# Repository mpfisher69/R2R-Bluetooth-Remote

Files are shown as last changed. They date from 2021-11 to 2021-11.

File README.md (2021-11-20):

<h1> Bluetooth Remote Controller</h1>
<p>For Reel-to-Reel tape recorders and vintage cassette decks.</p>
<p>Works with any open-reel (reel-to-reel) tape deck equipped with remote control connector, with active-low inputs</p>
It replicates functionality of original Technics remote controllers such as RP-9690 and RP-070 (including reverse-play function).</br>
Connects to remote controller input on Technics RS1500, RS1506 and RS1700 and also on Akai GX-635, GX-636, GX-747, GX-747DBX, GX-77 and also vintage cassette decks.</br>
This Bluetooth remote can be wired to other makes and models of tape machines, as long as they are equipped with a "tactile" tape transport buttons and "active-low" logic, such as Pioneer RT909.</p>

<p>Screenshots:<br>
<br>
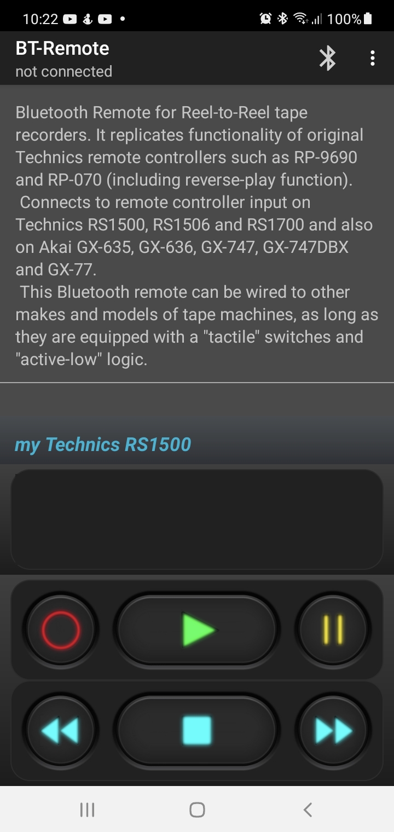
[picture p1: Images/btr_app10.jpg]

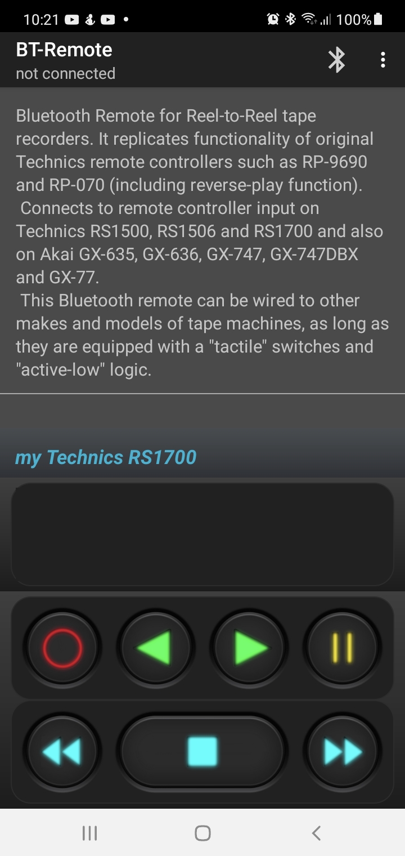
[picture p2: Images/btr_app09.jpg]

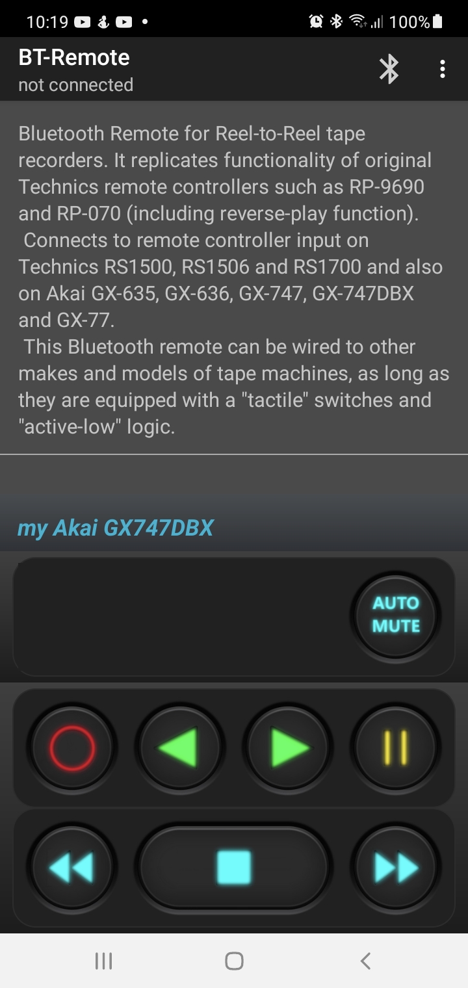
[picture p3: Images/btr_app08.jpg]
</p>
<p> I have some of the receivers fully built, if you don't want to build one yourself.<br>
Please <a href="mailto:audio@mpfisher.com">contact me</a> for details.<br>
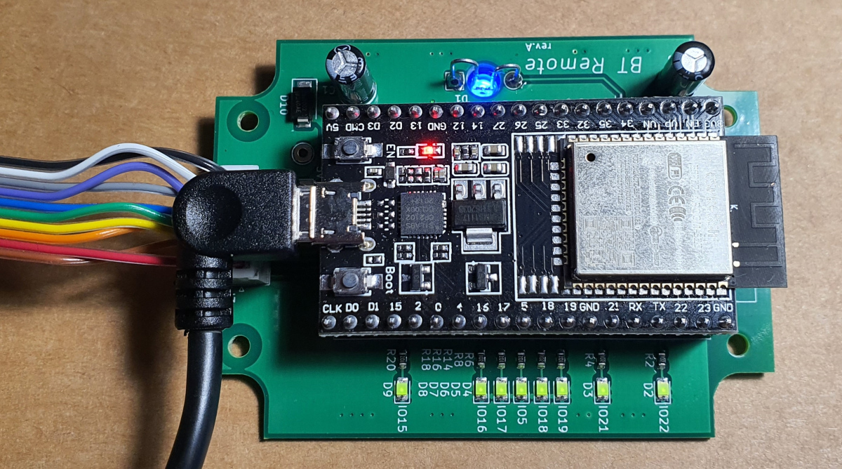
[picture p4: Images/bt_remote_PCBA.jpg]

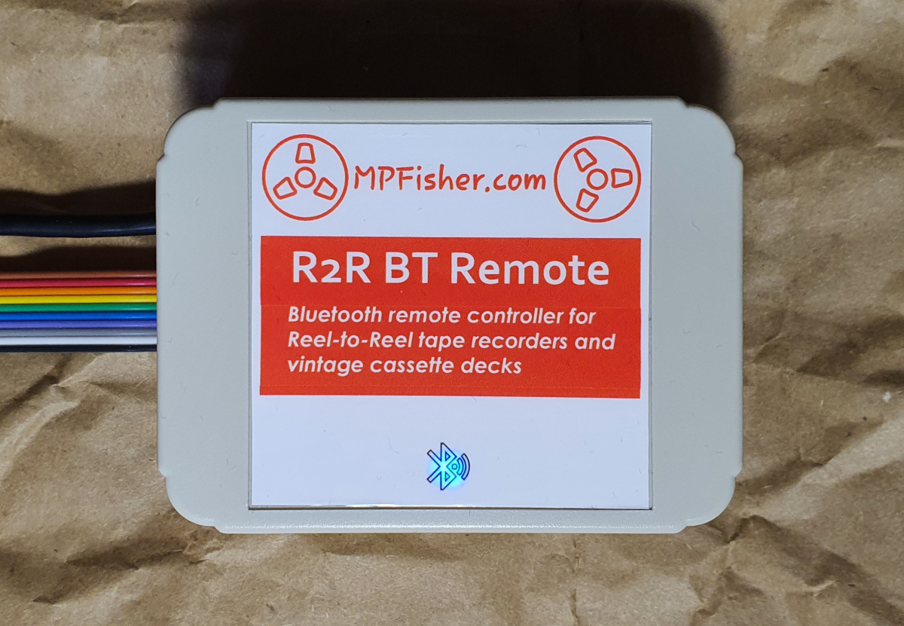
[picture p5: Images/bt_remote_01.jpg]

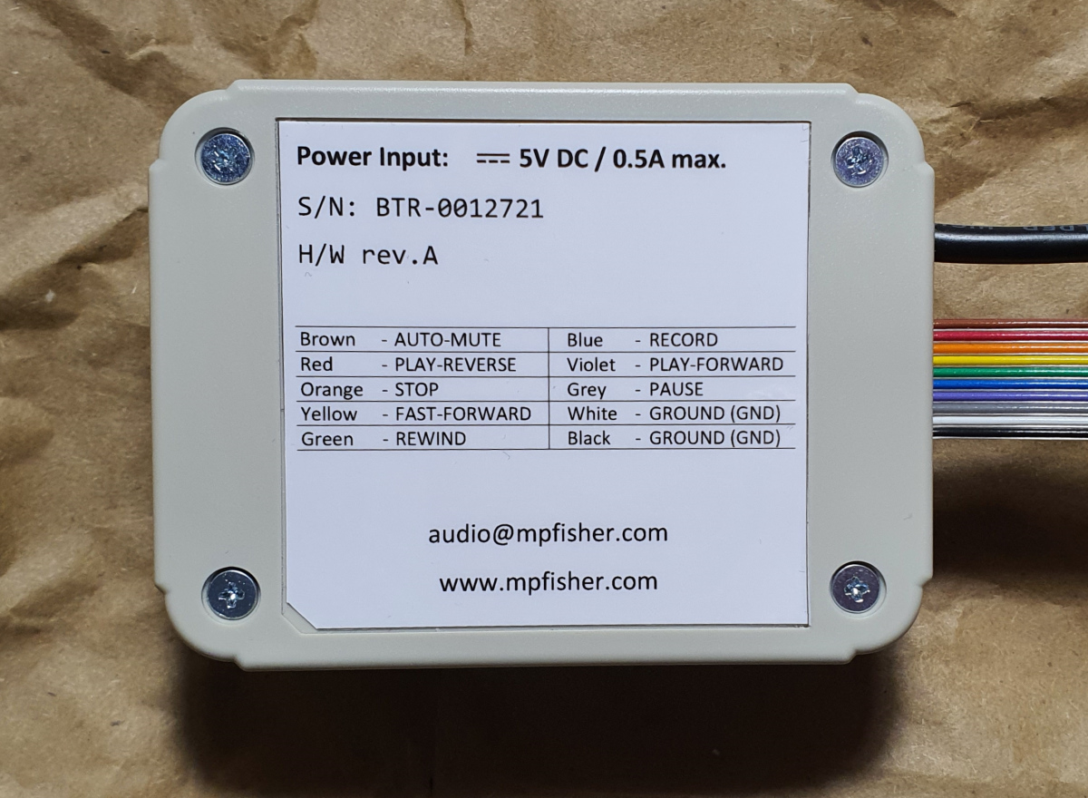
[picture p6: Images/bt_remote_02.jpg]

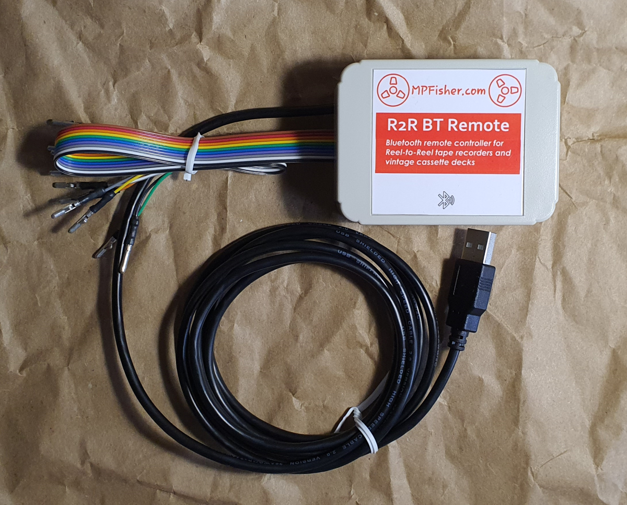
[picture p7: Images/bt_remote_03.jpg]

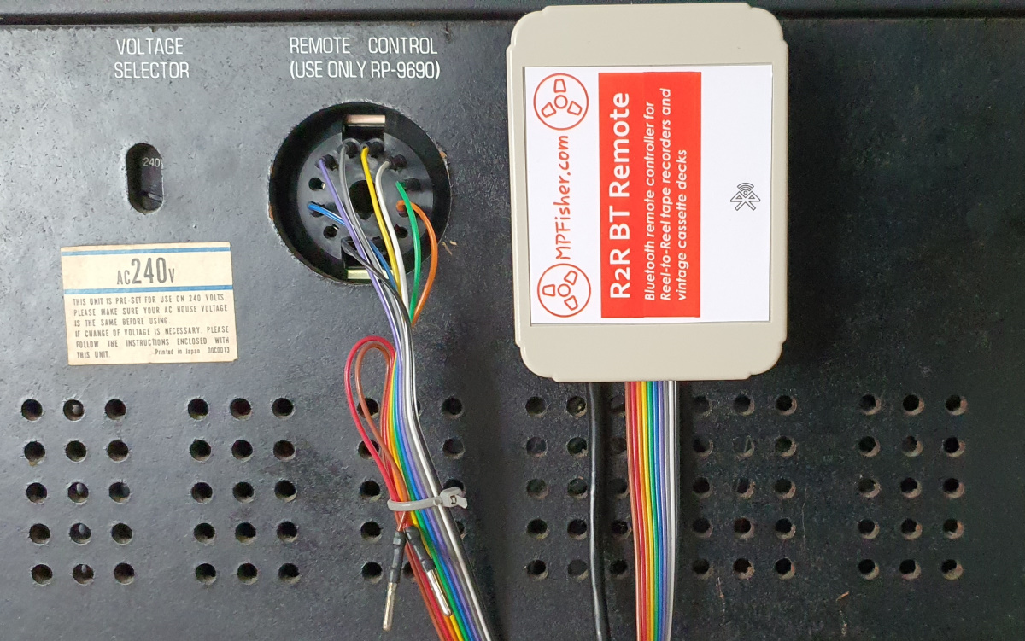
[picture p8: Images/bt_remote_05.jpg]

</p>

<p>Software is provided "as is" without any guarantee. I am looking for a colaborators who would want to develop it further and also help develop iOS app for iPhone/iPad.</p>
<p>To-Do:

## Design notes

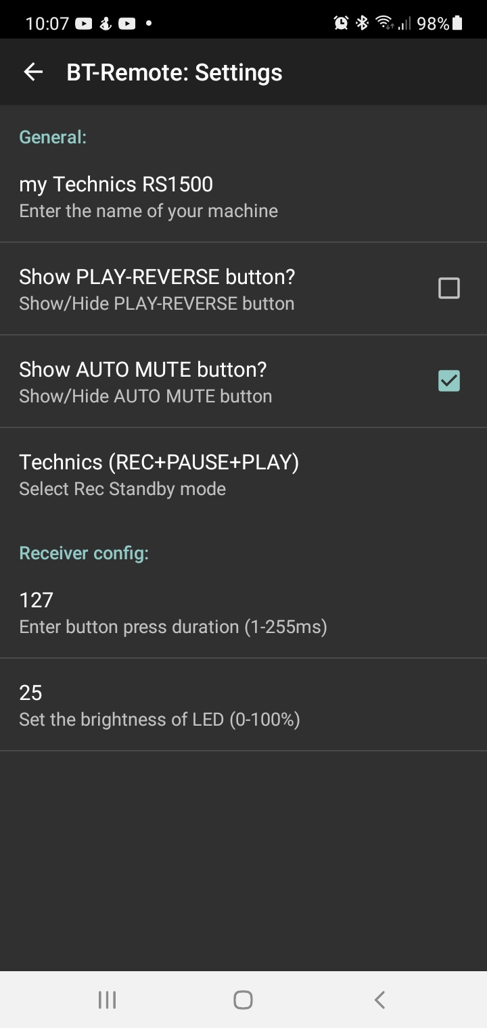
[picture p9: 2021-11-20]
Images/btr_app05.jpg

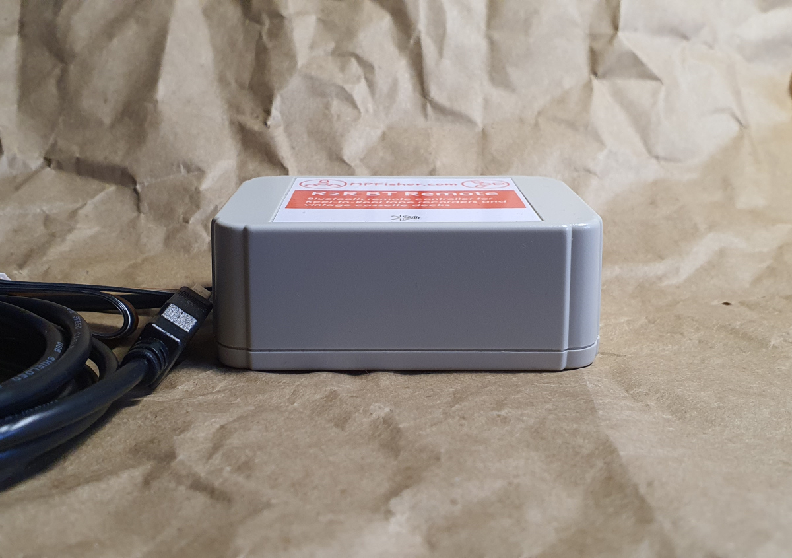
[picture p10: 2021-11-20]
Images/bt_remote_04.jpg

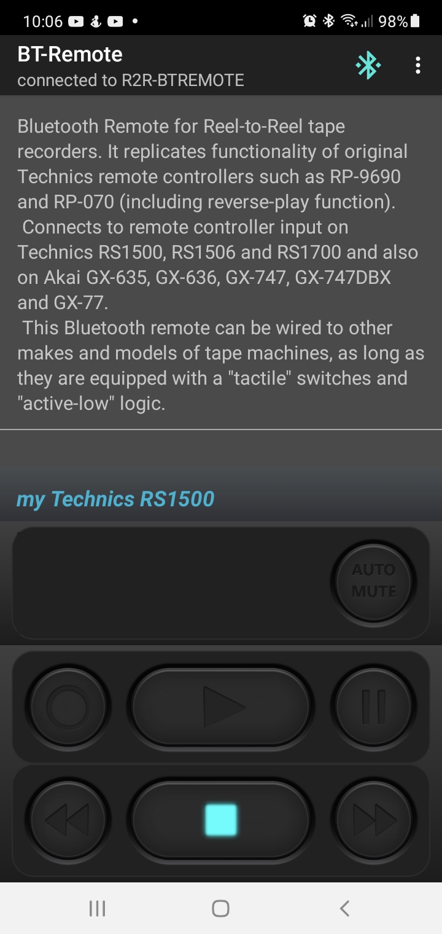
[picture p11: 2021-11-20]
Images/btr_app03.jpg

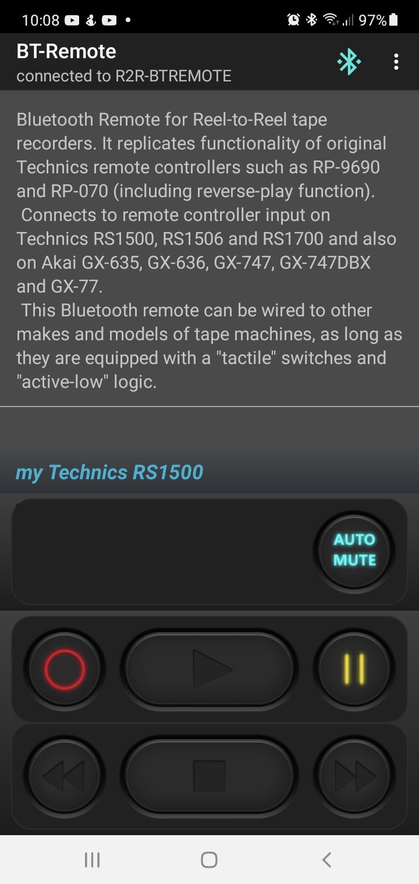
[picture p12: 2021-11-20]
Images/btr_app07.jpg

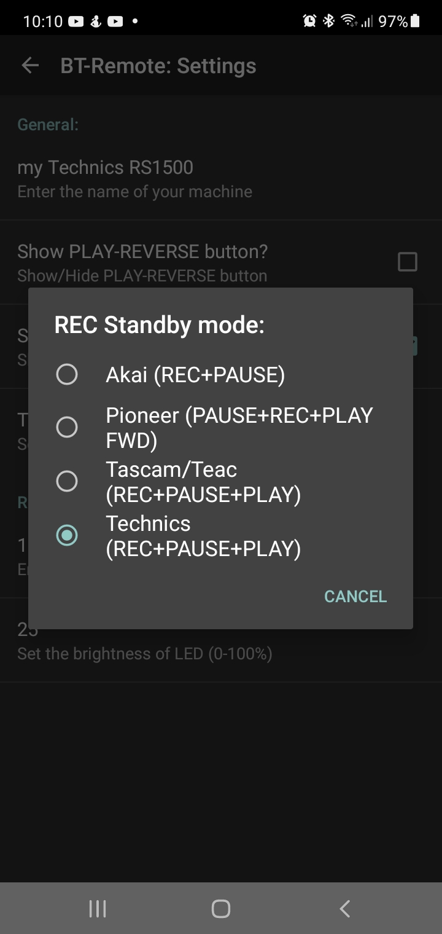
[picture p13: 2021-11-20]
Images/btr_app06.jpg

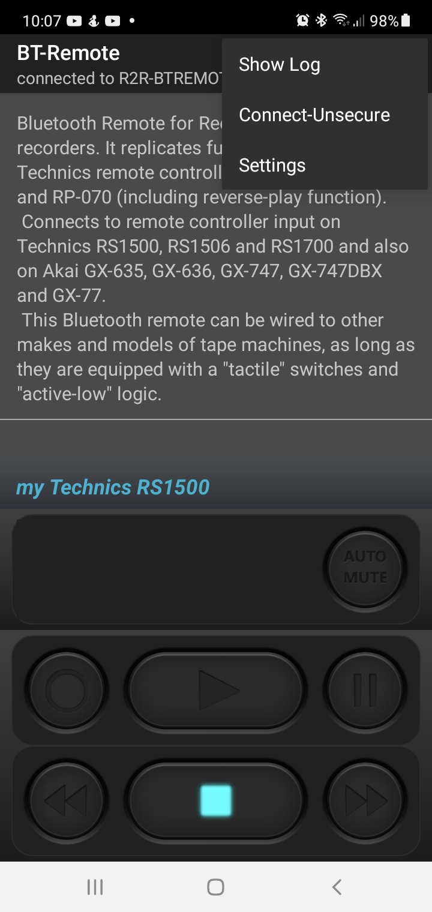
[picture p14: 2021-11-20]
Images/btr_app04.jpg

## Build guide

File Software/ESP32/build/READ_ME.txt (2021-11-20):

For ESP32 the flash must be written as follows:
erase range: 
0x8000 to 0x8FFF
0x1000 to 0x7FFF
0x10000 to 0xABFFF

0x8000: partition-table.bin
0x1000: bootloader.bin
0x10000: bt_remote.bin

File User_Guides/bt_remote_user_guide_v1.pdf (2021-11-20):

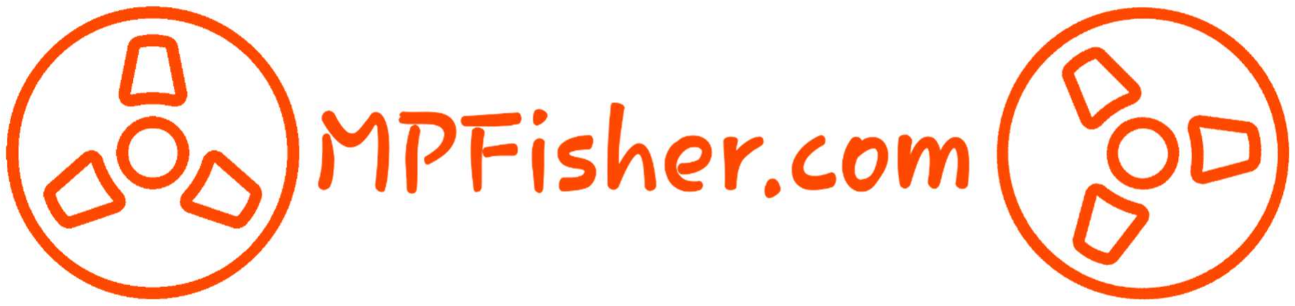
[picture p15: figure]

# R2R BT-Remote

## User Guide

ver.1
23/08/2021

## Hardware Installation

Switch off the power to the tape recorder and connect the receiver according to the wiring diagrams presented below.

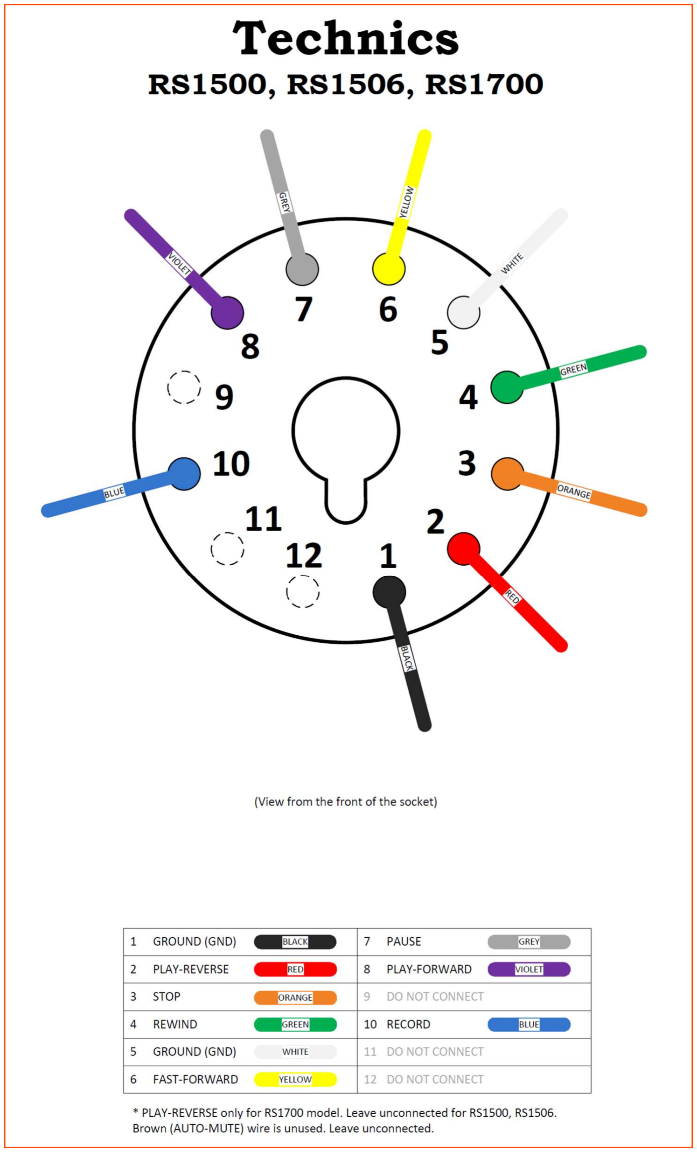
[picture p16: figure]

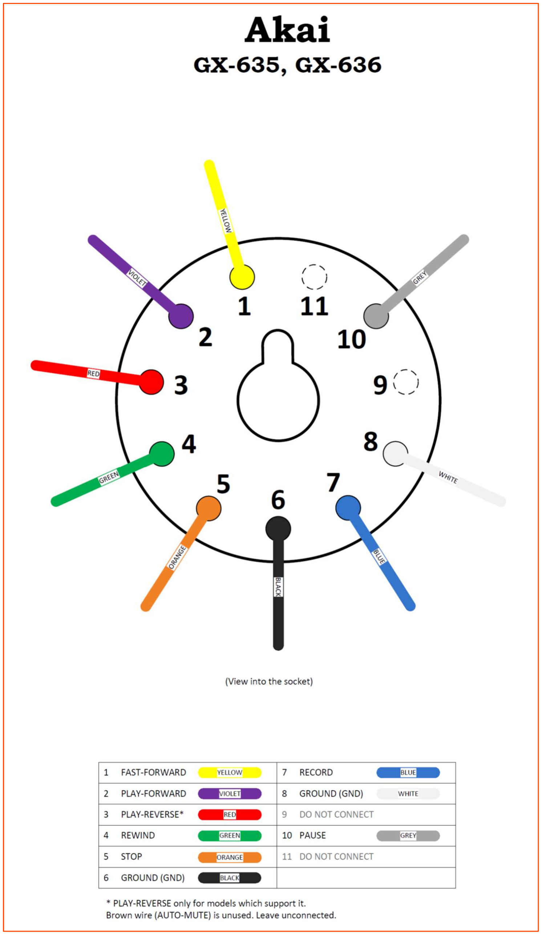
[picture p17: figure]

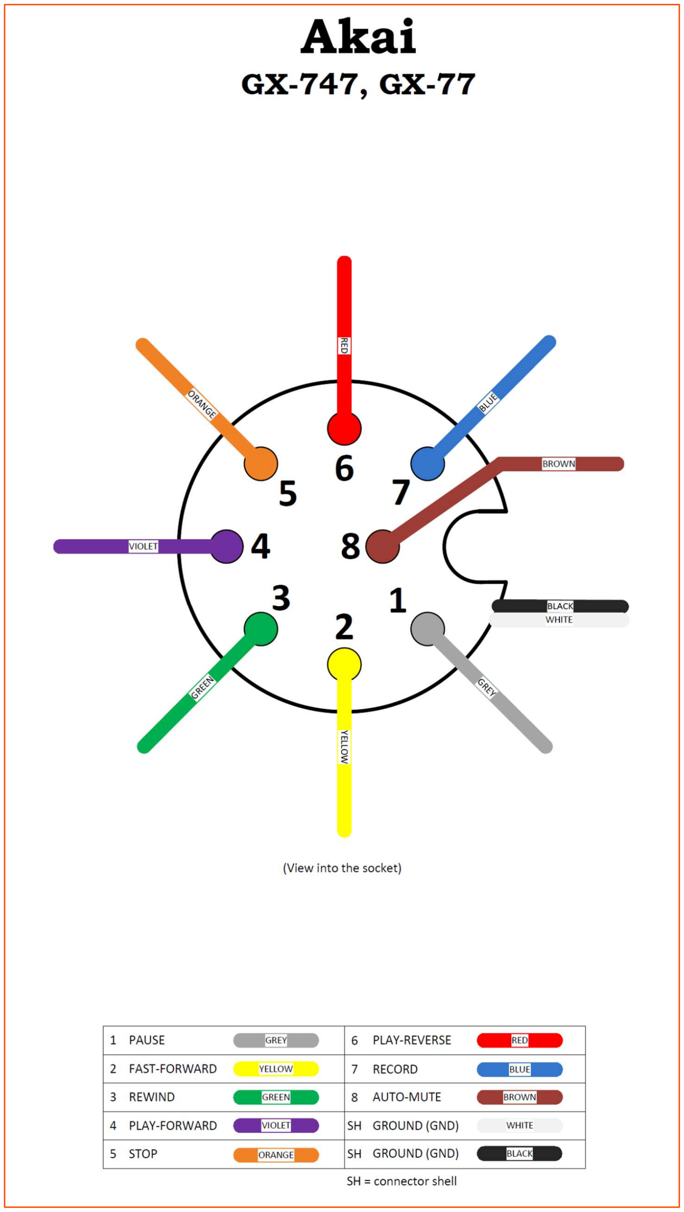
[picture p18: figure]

Connect USB cable from the receiver to a standard USB charger. Please note that the output of the charger must be rated for 5V / min. 0.5A (500mA).

Switch on the power to the tape recorder.

The blue LED underneath Bluetooth logo will start pulsing every second, indicating that the receiver is ready to accept the connection.

Please connect to the receiver from your Android device.

## Pairing the receiver

Open the Bluetooth settings on your Android device and tap “Scan”.

Find “R2R-BTREMOTE” in the list of available devices and tap on it to begin pairing.

Accept the default, randomly generated 6-digit pin code by tapping “Pair” button.

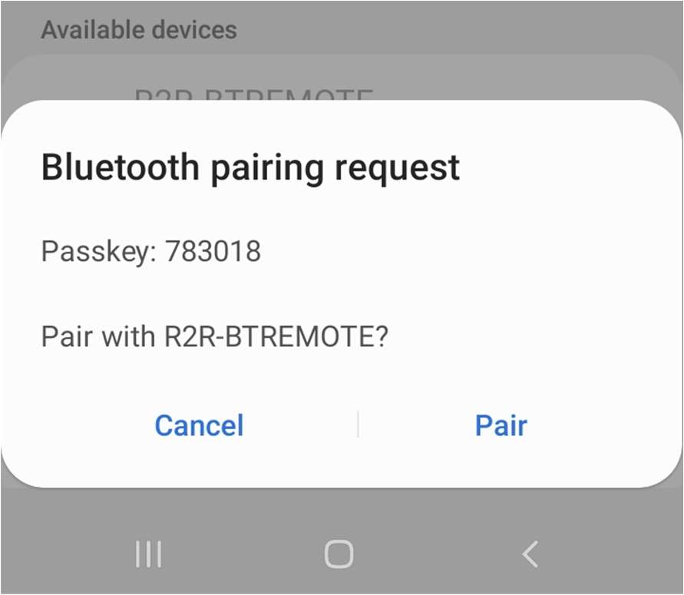
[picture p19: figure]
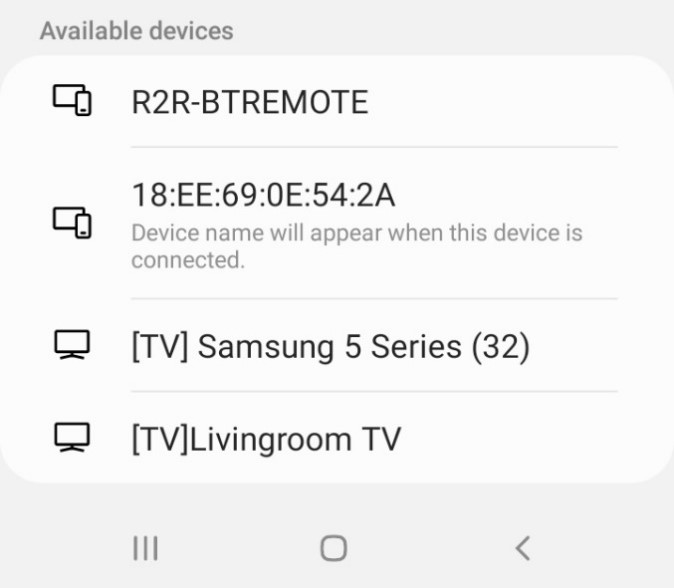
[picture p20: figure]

The receiver should be added to the list of paired devices.

Close Bluetooth settings window.

## Installing the Android app

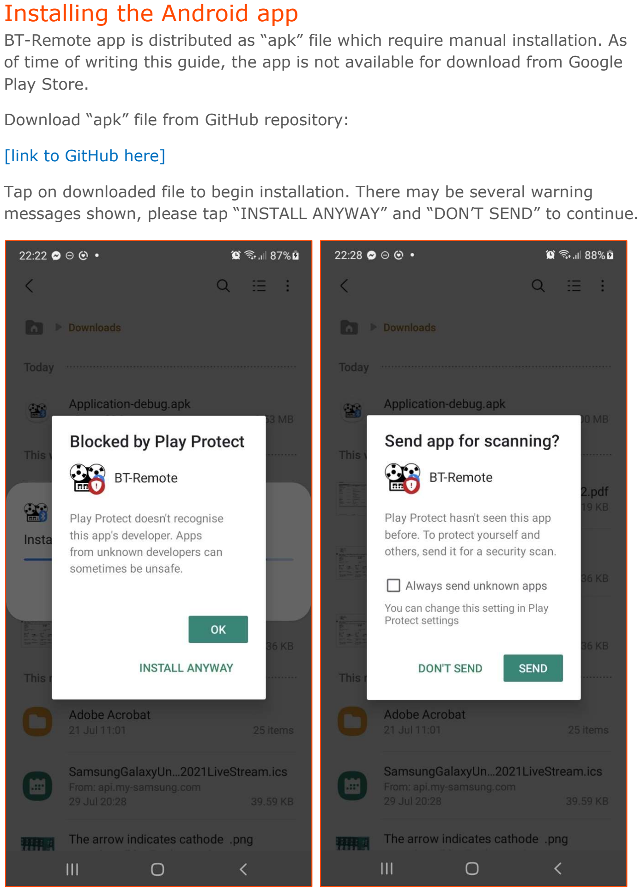
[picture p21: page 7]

BT-Remote app is distributed as “apk” file which require manual installation. As of time of writing this guide, the app is not available for download from Google Play Store.

Download “apk” file from GitHub repository:

[link to GitHub here]

Tap on downloaded file to begin installation. There may be several warning messages shown, please tap “INSTALL ANYWAY” and “DON’T SEND” to continue.

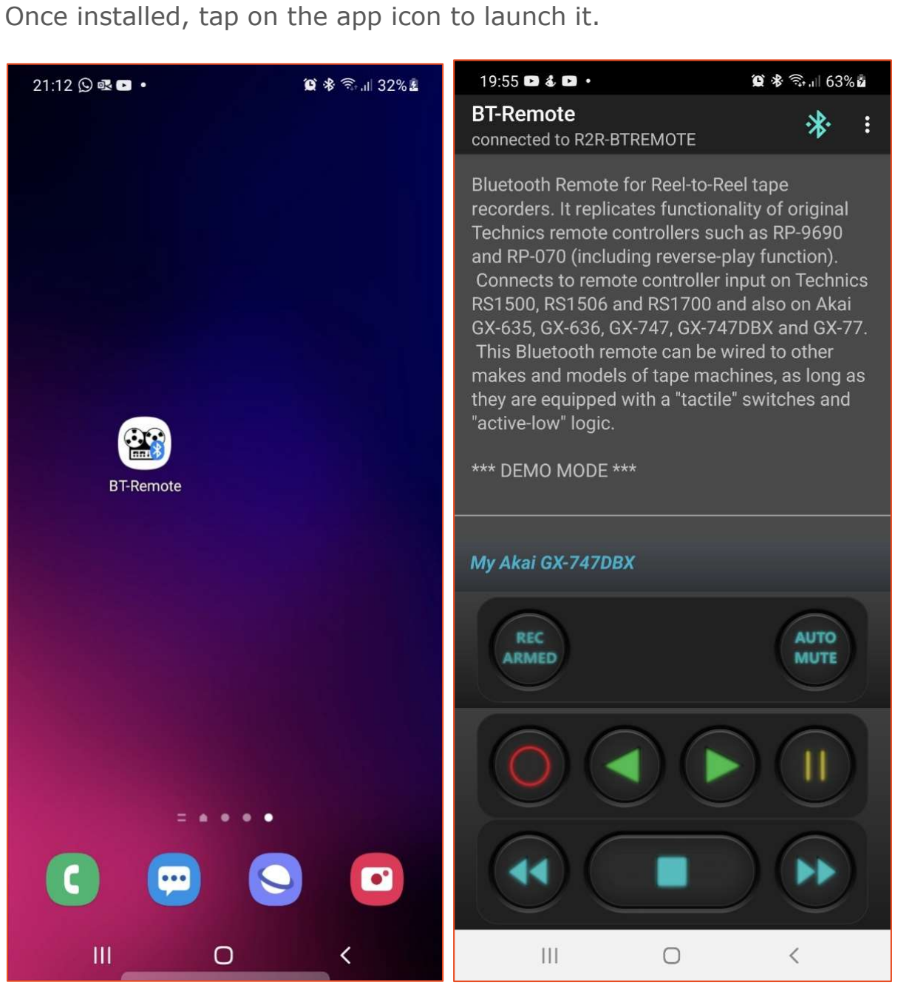
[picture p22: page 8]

Once installed, tap on the app icon to launch it.

## Setting up the app

Tap The three dots in the top-right corner of the screen and select “Settings”.

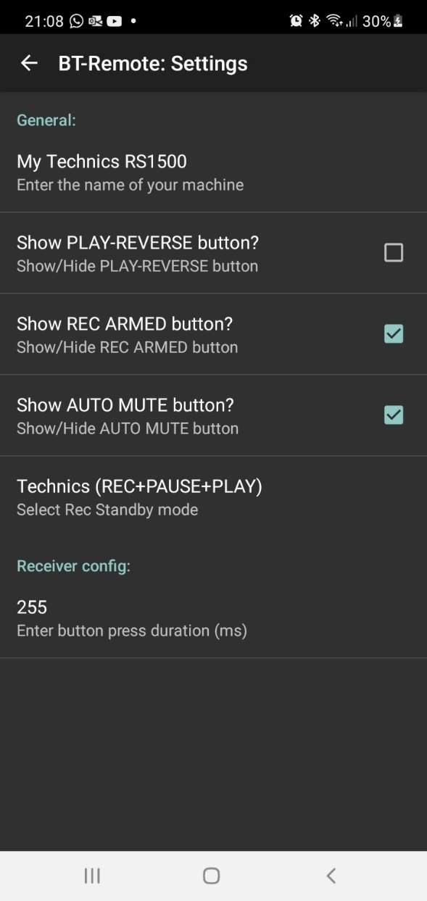
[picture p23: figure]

Options:

- Machine name: This is where you can set the text shown just above function buttons, on the main screen of the app. This option does not perform any function.
- Show PLAY-REVERSE button: If the receiver is connected to the tape recorder which support Play-Reverse function, please activate this option.
- Show REC ARMED button: Activate this option to prevent accidental recording. If this button is shown, it must be activated before Recording Standby function can be engaged.
- Show AUTO MUTE button: If the receiver is connected to the tape recorder which support Auto Mute function, please activate this option.

- Select Rec Standby mode: Different manufacturers of tape recorders have employed different methods of putting the tape recorder into recording standby mode, e.g.:
Technics [REC+PAUSE+PLAY]
Akai [REC+PAUSE]
- Button press duration: This option will configure for how long the receiver will emulate button press. It can be adjusted from 1ms to 255ms (milliseconds). This duration should be kept slightly higher than a minimum required to reliably register button press by the logic controller inside the tape recorder. 100ms is a value appropriate for most cases.

Close the settings screen and restart the app to send the new settings to the receiver.

## Connecting to the receiver

Tap on the Bluetooth icon in the top-right of the screen.

From the list of paired devices select R2R-BTREMOTE.

After few seconds the receiver should connect. Blue LED will start pulsing every 5 seconds to indicate ongoing connection.

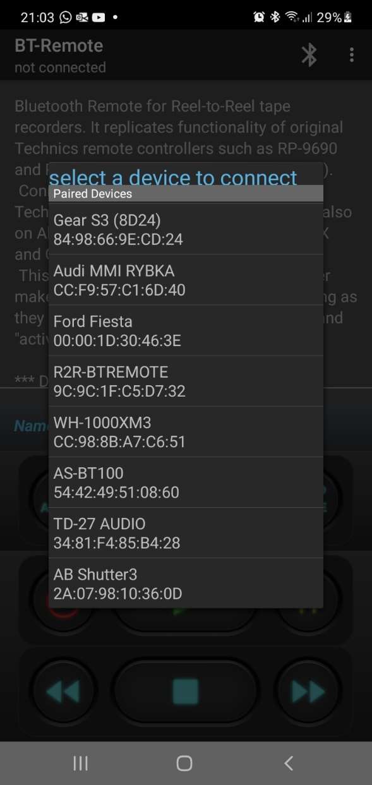
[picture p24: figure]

Please send your feedback to audio@mpfisher.com

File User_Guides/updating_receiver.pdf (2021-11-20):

# BT-REMOTE

### Updating the receiver

v.1

04/09/2021

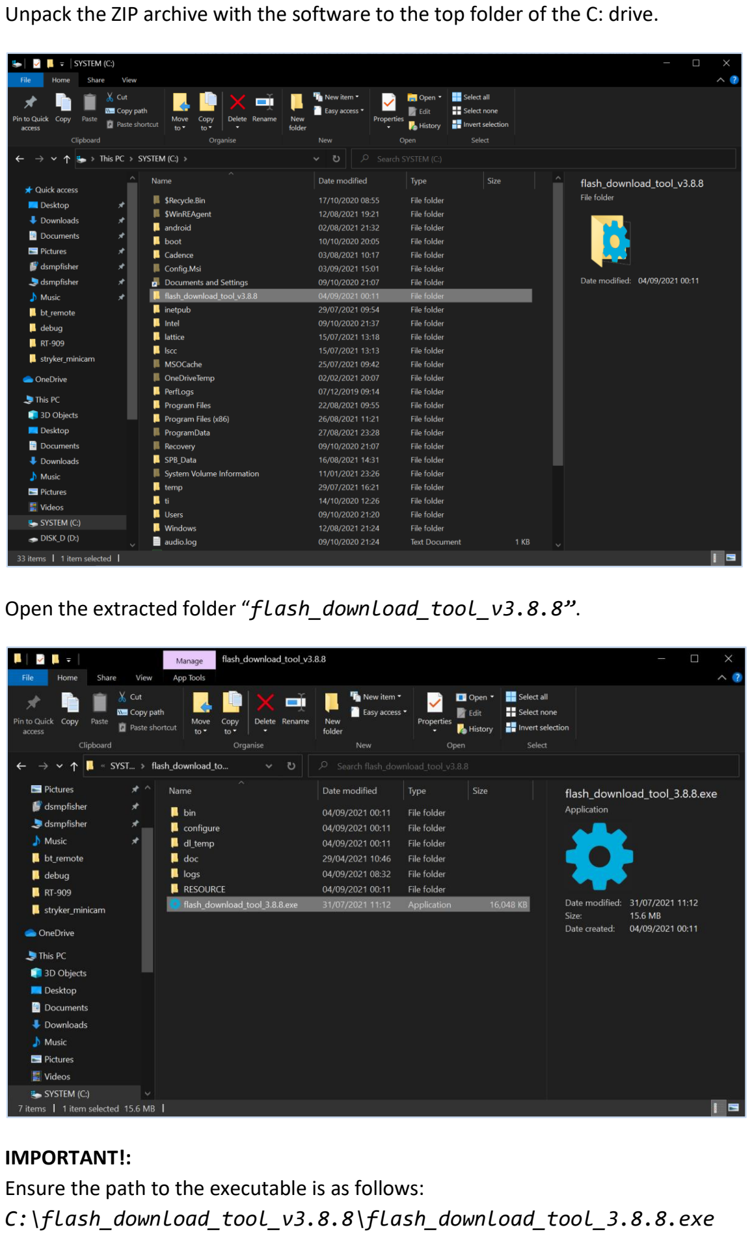
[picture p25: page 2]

Unpack the ZIP archive with the software to the top folder of the C: drive.

Open the extracted folder “flash_download_tool_v3.8.8”.

IMPORTANT!:
Ensure the path to the executable is as follows: C:\flash_download_tool_v3.8.8\flash_download_tool_3.8.8.exe

Connect the receiver to your PC and wait for the drivers to load.

Note the COM port number assigned to the receiver.

Run flash_download_tool_3.8.8.exe

In the dialog box select “ChipType” as “ESP32” and click “OK” button.

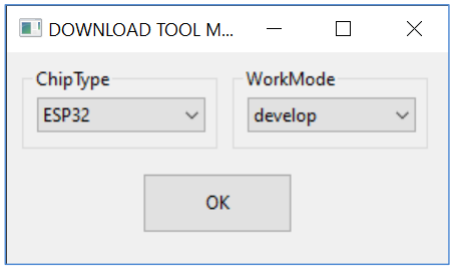
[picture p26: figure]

The main window should now open.

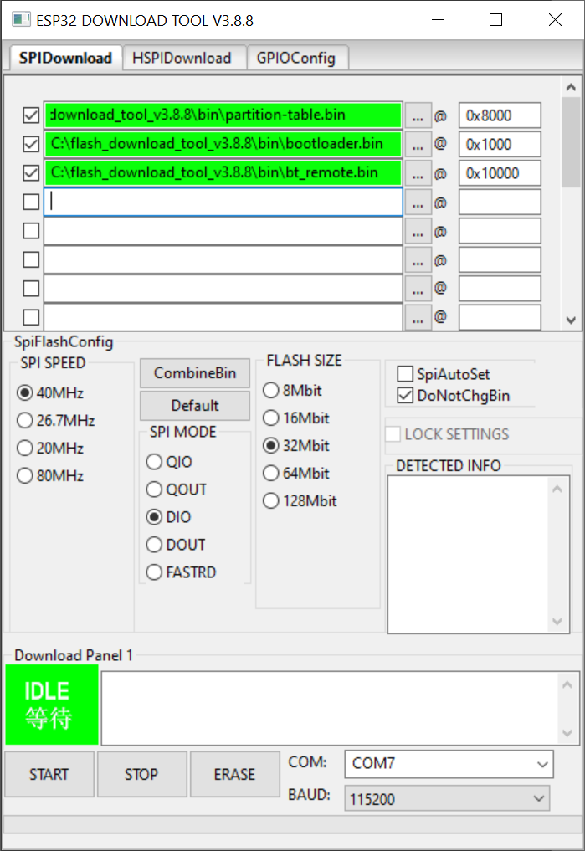
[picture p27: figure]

Ensure that the three lines indicating the flash files are not highlighted in red. They should be green or not highlighted at all. Red means that the path to the files is not setup correctly, e.g. the software is not in the following path:
C:\flash_download_tool_v3.8.8\flash_download_tool_3.8.8.exe

Select COM port number assigned to the receiver (e.g. COM7) and click “START” button.

The flashing process should take about 40 seconds to complete.

Disconnect the receiver from the PC and connect it again.

Blue LED on the receiver should start flashing every second.

Open TeraTerm terminal program and select COM port assigned to the receiver. Ensure that the baudrate is set to 115200.

If everything was done correctly, the following information should be visible in the terminal window (note the firmware version information).

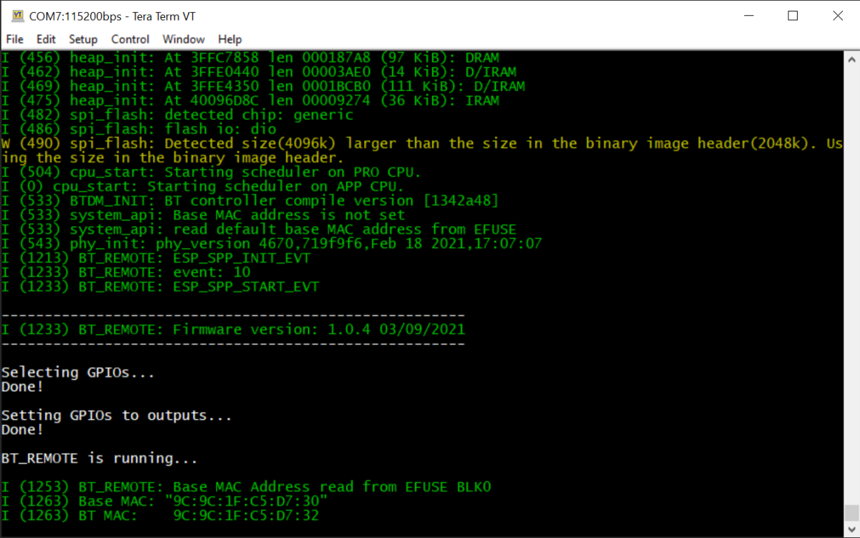
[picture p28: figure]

Terminal will show debug messages when the app is connected to the receiver. It may be useful for debugging the problems – if required.

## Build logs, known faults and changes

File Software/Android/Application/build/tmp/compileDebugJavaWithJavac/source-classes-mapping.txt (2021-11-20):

com/mpfisher/common/logger/LogWrapper.java
 com.mpfisher.common.logger.LogWrapper
com/mpfisher/common/activities/SampleActivityBase.java
 com.mpfisher.common.activities.SampleActivityBase
com/mpfisher/btremote/Utils.java
 com.mpfisher.btremote.Utils
 com.mpfisher.btremote.Utils$InputFilterHex
com/mpfisher/btremote/Constants.java
 com.mpfisher.btremote.Constants
com/mpfisher/common/logger/MessageOnlyLogFilter.java
 com.mpfisher.common.logger.MessageOnlyLogFilter
com/mpfisher/common/logger/LogNode.java
 com.mpfisher.common.logger.LogNode
com/mpfisher/btremote/BuildConfig.java
 com.mpfisher.btremote.BuildConfig
com/mpfisher/btremote/SettingsActivity.java
 com.mpfisher.btremote.SettingsActivity
com/mpfisher/btremote/BluetoothService.java
 com.mpfisher.btremote.BluetoothService
 com.mpfisher.btremote.BluetoothService$AcceptThread
 com.mpfisher.btremote.BluetoothService$ConnectThread
 com.mpfisher.btremote.BluetoothService$ConnectedThread
com/mpfisher/common/logger/LogFragment.java
 com.mpfisher.common.logger.LogFragment
 com.mpfisher.common.logger.LogFragment$1
com/mpfisher/common/logger/Log.java
 com.mpfisher.common.logger.Log
com/mpfisher/btremote/InputFilterMinMax.java
 com.mpfisher.btremote.InputFilterMinMax
com/mpfisher/common/logger/LogView.java
 com.mpfisher.common.logger.LogView
 com.mpfisher.common.logger.LogView$1
com/mpfisher/btremote/DeviceListActivity.java
 com.mpfisher.btremote.DeviceListActivity
 com.mpfisher.btremote.DeviceListActivity$1
 com.mpfisher.btremote.DeviceListActivity$2
com/mpfisher/btremote/BluetoothFragment.java
 com.mpfisher.btremote.BluetoothFragment
 com.mpfisher.btremote.BluetoothFragment$1
 com.mpfisher.btremote.BluetoothFragment$10
 com.mpfisher.btremote.BluetoothFragment$11
 com.mpfisher.btremote.BluetoothFragment$2
 com.mpfisher.btremote.BluetoothFragment$3
 com.mpfisher.btremote.BluetoothFragment$4
 com.mpfisher.btremote.BluetoothFragment$5
 com.mpfisher.btremote.BluetoothFragment$6
 com.mpfisher.btremote.BluetoothFragment$7
 com.mpfisher.btremote.BluetoothFragment$8
 com.mpfisher.btremote.BluetoothFragment$9
com/mpfisher/btremote/MainActivity.java
 com.mpfisher.btremote.MainActivity

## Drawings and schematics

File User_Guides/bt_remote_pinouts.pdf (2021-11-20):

# Technics

# RS1500, RS1506, RS1700

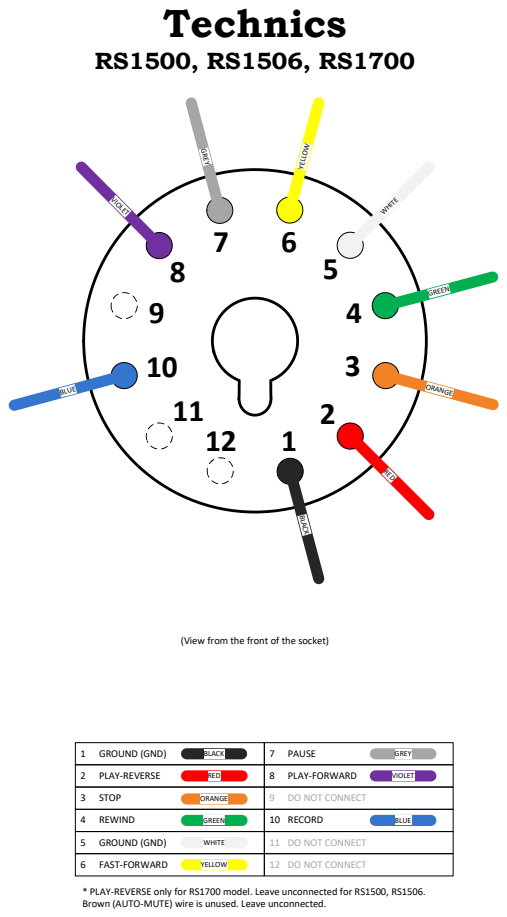
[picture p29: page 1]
1 BLACK; RED; ORANGE; GREEN; WHITE; YELLOW; GREY; VIOLET; BLUE; GROUND (GND); 2 PLAY-REVERSE; 3 STOP; 4 REWIND; 5 GROUND (GND); 6 FAST-FORWARD; BLACK; ORANGE GREEN WHITE; YEL O

EY VIOLET BLUE

(View from the front of the socket)

7 PAUSE
8 PLAY-FORWARD
9 DO NOT CONNECT
10 RECORD

11 DO NOT CONNECT
12 DO NOT CONNECT

* PLAY-REVERSE only for RS1700 model. Leave unconnected for RS1500, RS1506.
Brown (AUTO-MUTE) wire is unused. Leave unconnected.

# Akai

# GX-635, GX-636

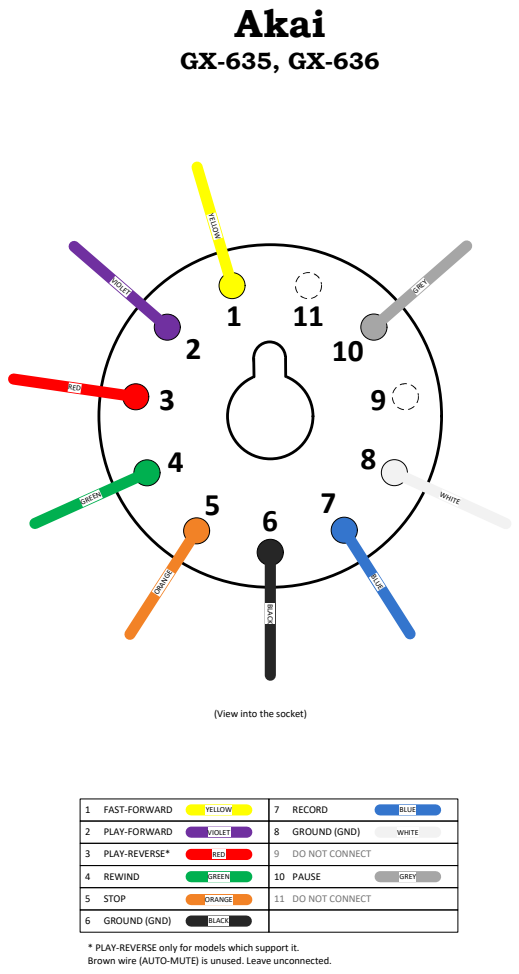
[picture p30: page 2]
RED; 3 PLAY-REVERSE*; 9 DO NOT CONNECT; 11 DO NOT CONNECT; GROUND (GND); BLACK; STOP; ORANGE; REWIND; GREEN; WHITE; FAST-FORWARD; YELLOW; PLAY-FORWARD; VIOLET; PAUSE; GREY; RECORD; BLUE; 11 BLACK; YEL OW; VIOLET BLUE

RED ORANGE GREEN WHITE

(View into the socket)

* PLAY-REVERSE only for models which support it.
Brown wire (AUTO-MUTE) is unused. Leave unconnected.

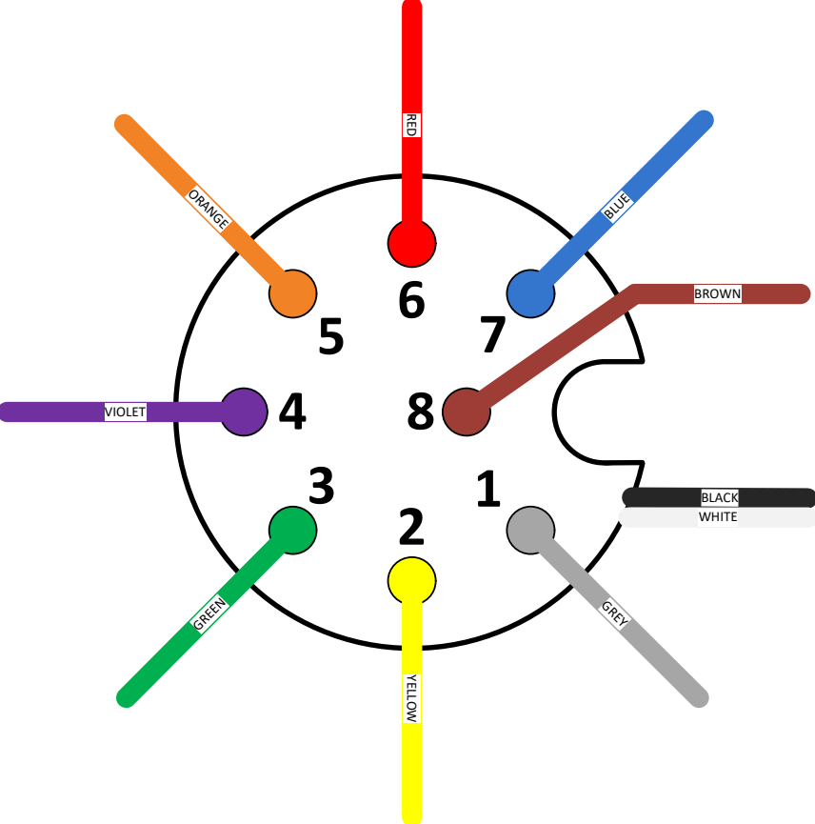
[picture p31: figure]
8 BLACK RED; ORANGE GRE N; WHITE YELLOW; GREY; VIOLET; BLUE; BROWN

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
STOP | ORANGE | GROUND (GND) | BLACK
REWIND | GREEN
GROUND (GND) | WHITE
FAST-FORWARD | YELLOW
PLAY-FORWARD | VIOLET
PAUSE | GREY
RECORD | BLUE

# Akai

# GX-747, GX-77

(View into the socket)

PLAY-REVERSE | RED
AUTO-MUTE | BROWN
SH
SH
SH = connector shell

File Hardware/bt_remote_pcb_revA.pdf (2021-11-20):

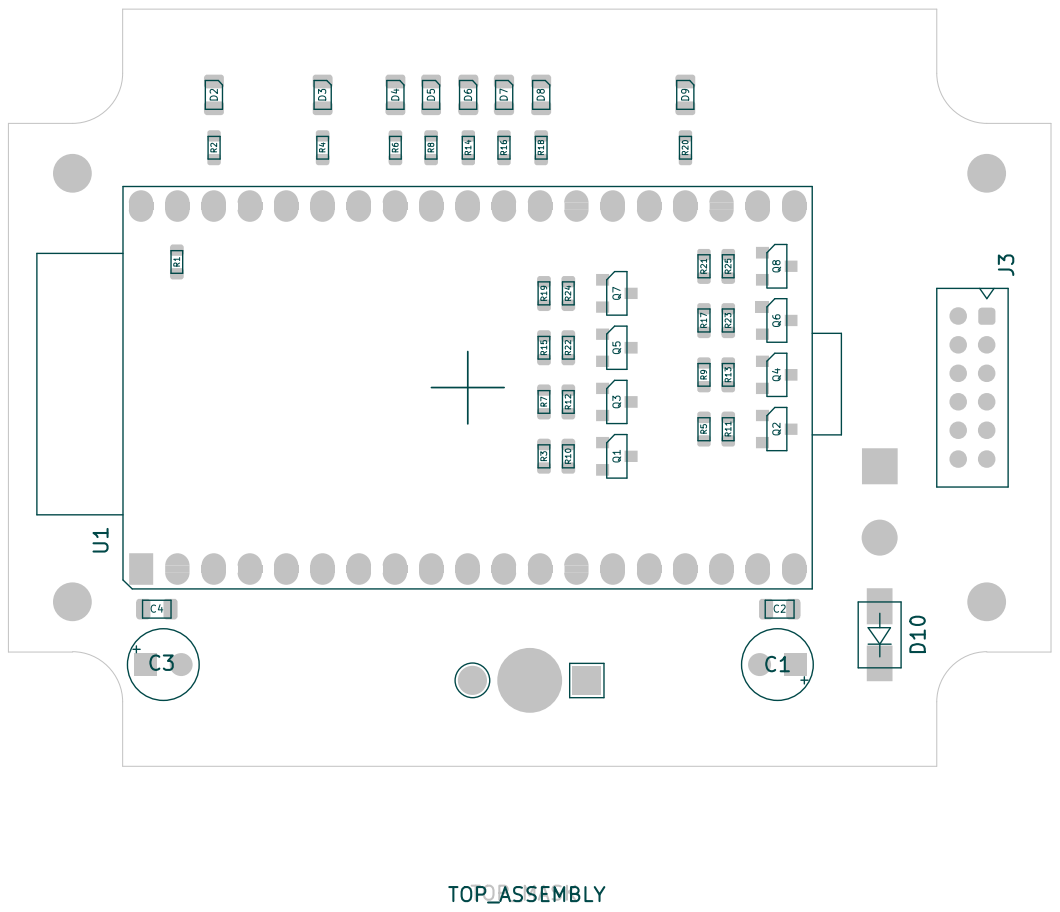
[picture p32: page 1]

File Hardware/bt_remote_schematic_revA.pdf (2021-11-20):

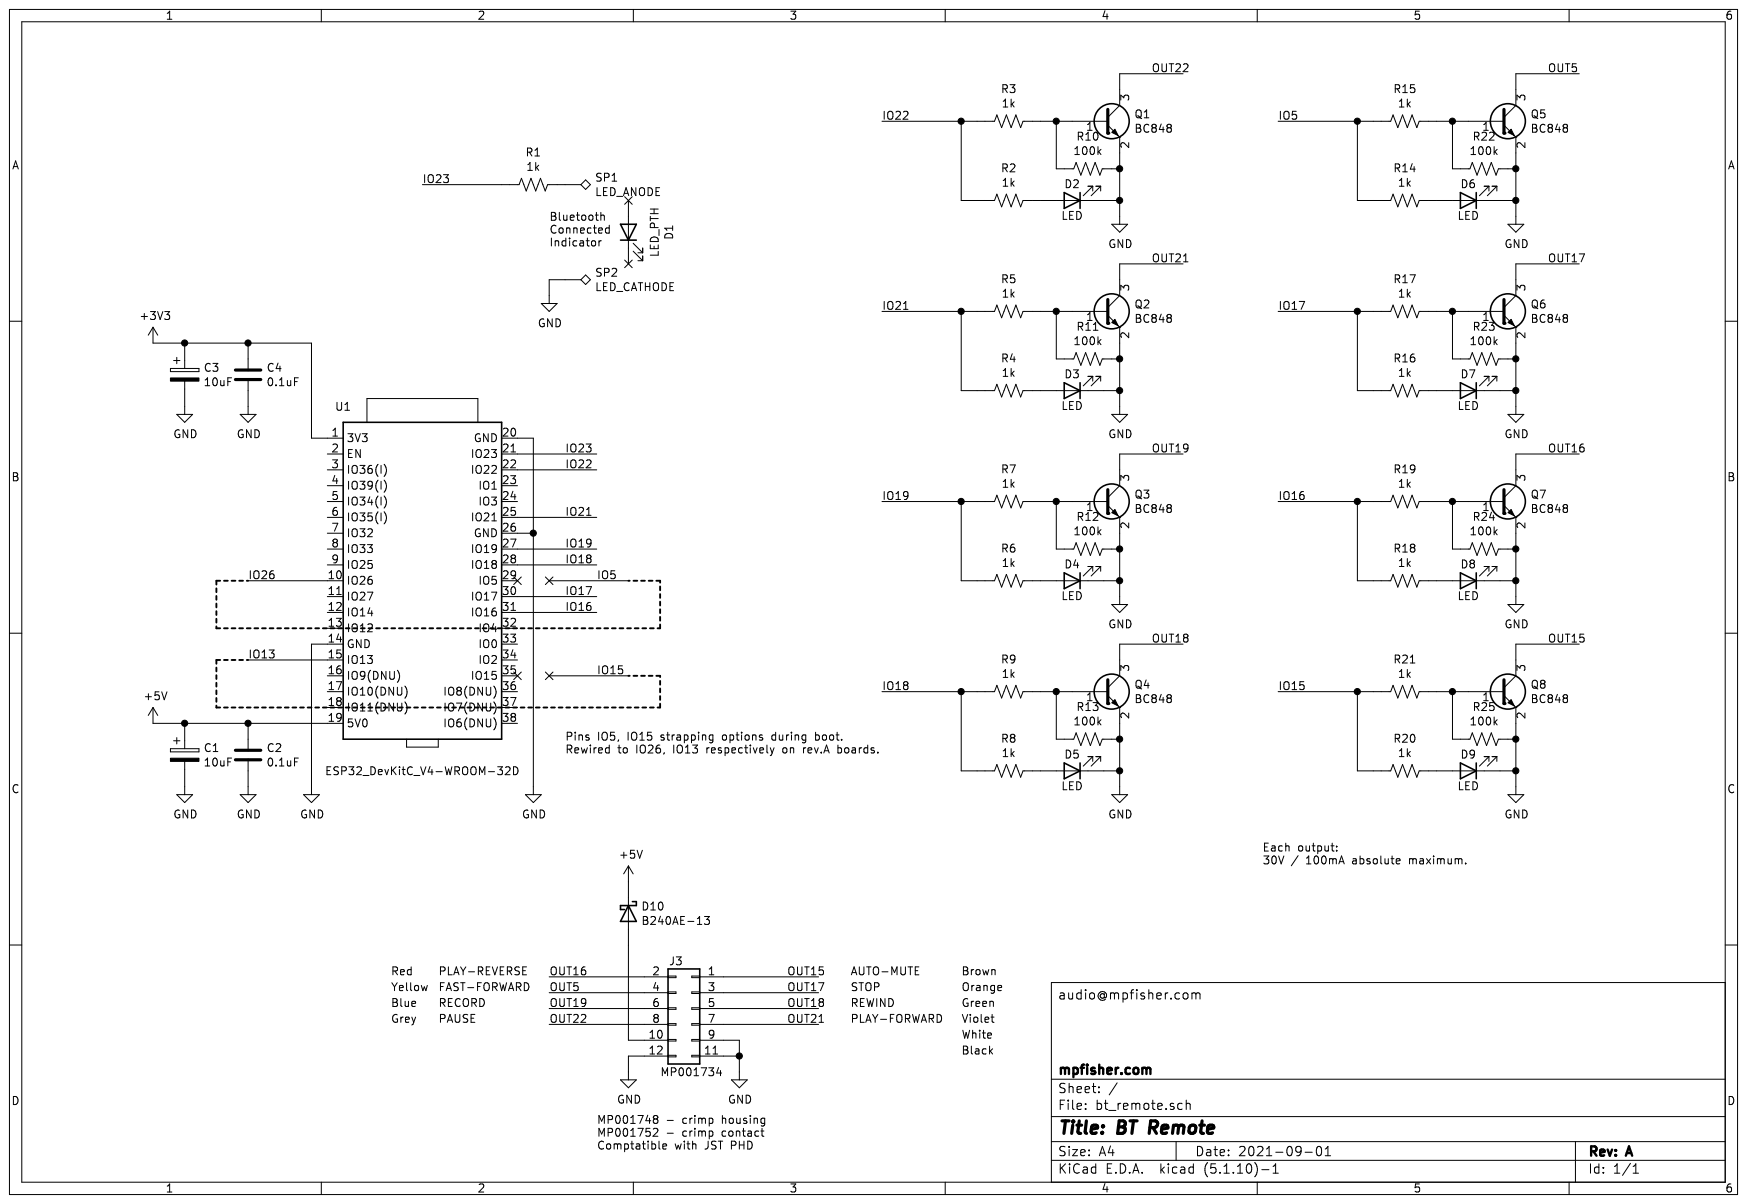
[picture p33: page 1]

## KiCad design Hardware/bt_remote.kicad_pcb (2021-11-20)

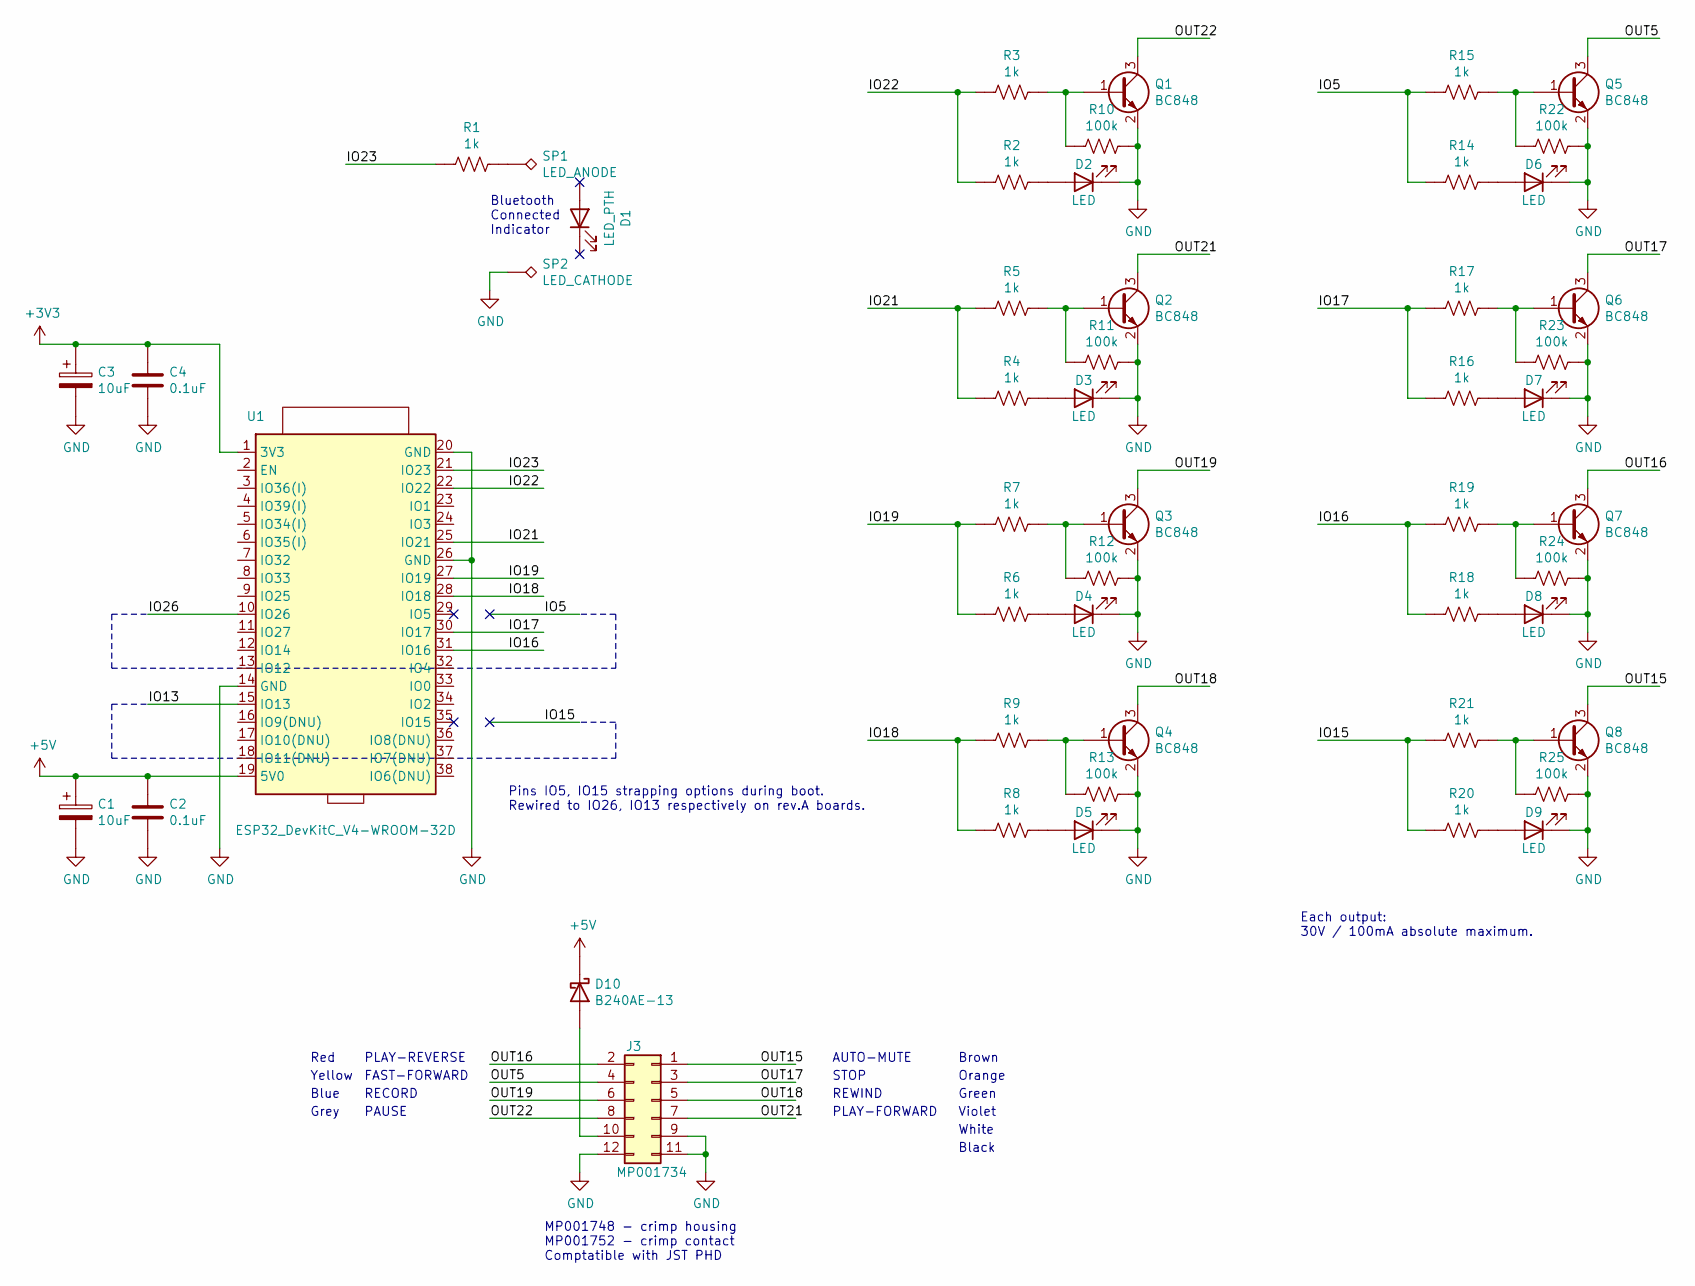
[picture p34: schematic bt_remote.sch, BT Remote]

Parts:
C1, C3: 10uF; CP_Radial_D5.0mm_P2.50mm
C2, C4: 0.1uF; C_0805_2012Metric
D1: LED_PTH
D2, D3, D4, D5, D6, D7, D8, D9: LED; LED_0805_2012Metric
D10: B240AE-13; D_SMA
J3: MP001734; JST_PHD_B12B-PHDSS_2x06_P2.00mm_Vertical
Q1, Q2, Q3, Q4, Q5, Q6, Q7, Q8: BC848; SOT-23
R1, R2, R3, R4, R5, R6, R7, R8, R9, R14, R15, R16, R17, R18, R19, R20, R21: 1k; R_0603_1608Metric
R10, R11, R12, R13, R22, R23, R24, R25: 100k; R_0603_1608Metric
SP1: LED_ANODE; TestPoint_THTPad_D2.0mm_Drill1.0mm
SP2: LED_CATHODE; TestPoint_THTPad_2.0x2.0mm_Drill1.0mm
U1: ESP32_DevKitC_V4-WROOM-32D; ESP32-DevKitC_v4

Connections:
+3V3: C3.1, C4.1, U1.1 (3V3)
+5V: C1.1, C2.1, D10.1 (K), U1.19 (5V0)
/IO5: R14.2, R15.2, U1.29 (IO5)
/IO15: R20.2, R21.2, U1.35 (IO15)
/IO16: R18.2, R19.2, U1.31 (IO16)
/IO17: R16.2, R17.2, U1.30 (IO17)
/IO18: R8.2, R9.2, U1.28 (IO18)
/IO19: R6.2, R7.2, U1.27 (IO19)
/IO21: R4.2, R5.2, U1.25 (IO21)
/IO22: R2.2, R3.2, U1.22 (IO22)
/IO23: R1.2, U1.21 (IO23)
/OUT5: J3.4, Q5.3 (C)
/OUT15: J3.1, Q8.3 (C)
/OUT16: J3.2, Q7.3 (C)
/OUT17: J3.3, Q6.3 (C)
/OUT18: J3.5, Q4.3 (C)
/OUT19: J3.6, Q3.3 (C)
/OUT21: J3.7, Q2.3 (C)
/OUT22: J3.8, Q1.3 (C)
GND: C1.2, C2.2, C3.2, C4.2, D2.1 (K), D3.1 (K), D4.1 (K), D5.1 (K), D6.1 (K), D7.1 (K), D8.1 (K), D9.1 (K), J3.9, J3.11, J3.12, Q1.2 (E), Q2.2 (E), Q3.2 (E), Q4.2 (E), Q5.2 (E), Q6.2 (E), Q7.2 (E), Q8.2 (E), R10.1, R11.1, R12.1, R13.1, R22.1, R23.1, R24.1, R25.1, SP2.1, U1.14 (GND), U1.20 (GND), U1.26 (GND)
unnamed: D2.2 (A), R2.1
unnamed: D3.2 (A), R4.1
unnamed: D4.2 (A), R6.1
unnamed: D5.2 (A), R8.1
unnamed: D6.2 (A), R14.1
unnamed: D7.2 (A), R16.1
unnamed: D8.2 (A), R18.1
unnamed: D9.2 (A), R20.1
unnamed: D10.2 (A), J3.10
unnamed: Q1.1 (B), R3.1, R10.2
unnamed: Q2.1 (B), R5.1, R11.2
unnamed: Q3.1 (B), R7.1, R12.2
unnamed: Q4.1 (B), R9.1, R13.2
unnamed: Q5.1 (B), R15.1, R22.2
unnamed: Q6.1 (B), R17.1, R23.2
unnamed: Q7.1 (B), R19.1, R24.2
unnamed: Q8.1 (B), R21.1, R25.2
unnamed: R1.1, SP1.1

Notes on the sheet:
PLAY-REVERSE
STOP
REWIND
FAST-FORWARD
PAUSE
PLAY-FORWARD
RECORD
AUTO-MUTE
Bluetooth Connected Indicator
MP001748 - crimp housing MP001752 - crimp contact Comptatible with JST PHD
Each output: 30V / 100mA absolute maximum.
Green
Violet
Brown
Orange
Red
Yellow
Grey
Blue
White
Black
Pins IO5, IO15 strapping options during boot. Rewired to IO26, IO13 respectively on rev.A boards.

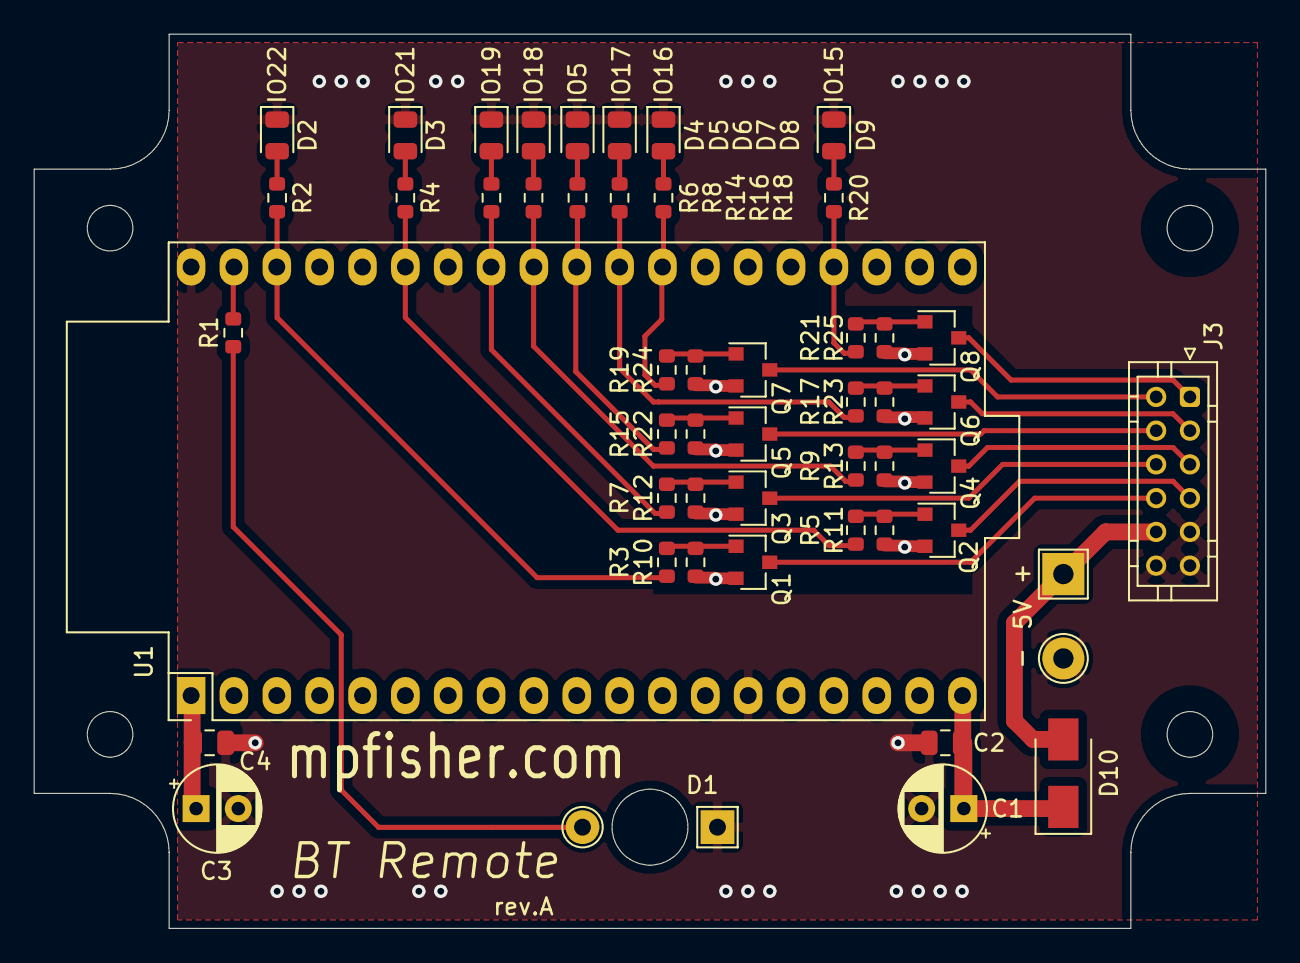
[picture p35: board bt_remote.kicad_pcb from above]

Board: 2 copper layers, 73.0 x 53.0 mm, 50 parts (0 on the bottom side), 38 nets.

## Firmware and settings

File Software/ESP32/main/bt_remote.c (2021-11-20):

/*
   Bluetooth Remote Controller for Reel-to-Reel tape players and cassette decks.

   This software is distributed on an "AS IS" BASIS, WITHOUT WARRANTIES OR
   CONDITIONS OF ANY KIND, either express or implied.
*/

/*
   TODO:
   Implement two-way communication to keep state machines synchronised between app and BT module.


   Figure out some nice method to handle all these different "REC STANDBY" methods,
   i.e. Technics RS1500 require REC+PAUSE+PLAY. Akai require REC+PAUSE.


*/

#include <stdint.h>
#include <string.h>
#include <stdbool.h>
#include <stdio.h>
#include "nvs.h"
#include "nvs_flash.h"
#include "freertos/FreeRTOS.h"
#include "freertos/task.h"
#include "esp_log.h"
#include "esp_bt.h"
#include "esp_bt_main.h"
#include "esp_gap_bt_api.h"
#include "esp_bt_device.h"
#include "esp_spp_api.h"

#include "time.h"
#include "sys/time.h"

#include "esp_system.h"
#include "esp_spi_flash.h"
#include "driver/gpio.h"
#include "driver/ledc.h"


/* LED PWM */
#define LEDC_HS_TIMER          LEDC_TIMER_0
#define LEDC_HS_MODE           LEDC_HIGH_SPEED_MODE
#define LEDC_HS_CH0_GPIO       (23)
#define LEDC_HS_CH0_CHANNEL    LEDC_CHANNEL_0
#define LEDC_DUTY_RES          (1023)


/* GPIO assignments. */
#define GPIO_PLAY_FWD	 21
#define GPIO_PLAY_REV	 16
#define GPIO_STOP		 17
#define GPIO_FFWD		 26 // Pin updated - IO5 was PU. Wire mod on rev.A boards.
#define GPIO_REW		 18
#define GPIO_REC		 19
#define GPIO_AUTO_MUTE	 13 // Pin updated - IO15 was PU. Wire mod on rev.A boards.
#define GPIO_PAUSE		 22
#define GPIO_BT_OPEN	 23 // Bluetooth connection LED indicator

#define CMD_REC_FWD      0x01
#define CMD_REC_REV      0x02
#define CMD_PAUSE        0x03
#define CMD_PLAY_FWD     0x04
#define CMD_PLAY_REV     0x05
#define CMD_STOP         0x06
#define CMD_FFWD         0x07
#define CMD_REW          0x08
#define CMD_AUTO_MUTE    0x09
#define CMD_TRANSPORT_FUNCTION  0xAA

#define CMD_SET_DELAY			 0xBA
#define CMD_SET_PWM				 0xCA
#define CMD_SET_REC_STDBY_MODE   0xBB
/* To engage recording standby on Technics machines,
   the following button sequence must be executed:
   REC + PAUSE + PLAY_FWD or PLAY_REV
   then, PLAY_FWD or PLAY_REV to start recording */
#define REC_STDBY_MODE_TECHNICS  0x01
/* To engage recording standby on Akai machines,
   the following button sequence must be executed:
   REC + PAUSE
   then, PLAY_FWD or PLAY_REV to start recording */
#define REC_STDBY_MODE_AKAI      0x02
#define REC_STDBY_MODE_PIONEER   0x04
#define REC_STDBY_MODE_TASCAM    0x08

#define ACK = 0xFE;

#define SPP_TAG				"BT_REMOTE"
#define SPP_SERVER_NAME		"R2R-BTR_SERVER"
#define DEVICE_NAME	 		"R2R-BTREMOTE"
#define SPP_SHOW_DATA 		 0
#define SPP_SHOW_SPEED		 1
#define SPP_SHOW_MODE		 SPP_SHOW_DATA    /*Choose show mode: show data or speed*/

#define APP_VERSION			"1.0.8. 26/09/2021"

static const esp_spp_mode_t esp_spp_mode = ESP_SPP_MODE_CB;

//static struct timeval time_new, time_old;

static const esp_spp_sec_t sec_mask = ESP_SPP_SEC_AUTHENTICATE;
static const esp_spp_role_t role_slave = ESP_SPP_ROLE_SLAVE;

uint8_t	 bt_data[64] = {0};
uint8_t	 bt_data_len = 0;
char	 bt_open = false;
uint8_t	 cmdDelay = 100; // For how long pin should be in active state (1...255ms)
//uint8_t	 cmdPWM = 100; // BT LED brightness (0...100%)
uint8_t	 play_direction = CMD_PLAY_FWD; // Keep track of play direction
uint8_t	 rec_stby_mode = REC_STDBY_MODE_TECHNICS; // Variable to store record standby mode received from the app
unsigned int ledc_duty = LEDC_DUTY_RES;

// Tape transport control state machine
static void send_ctrl(char data)
{
		switch (data) {
			case CMD_PLAY_FWD:
		        ESP_LOGI(SPP_TAG, "PLAY_FWD received");
				gpio_set_level(GPIO_PLAY_FWD, 1);
				vTaskDelay(cmdDelay / portTICK_PERIOD_MS);
				gpio_set_level(GPIO_PLAY_FWD, 0);
				play_direction = CMD_PLAY_FWD;
				break;
			case CMD_PLAY_REV:
		        ESP_LOGI(SPP_TAG, "PLAY_REV received");
				gpio_set_level(GPIO_PLAY_REV, 1);
				vTaskDelay(cmdDelay / portTICK_PERIOD_MS);
				gpio_set_level(GPIO_PLAY_REV, 0);
				play_direction = CMD_PLAY_REV;
				break;
			case CMD_STOP:
		        ESP_LOGI(SPP_TAG, "STOP received");
				gpio_set_level(GPIO_STOP, 1);
				vTaskDelay(cmdDelay / portTICK_PERIOD_MS);
				gpio_set_level(GPIO_STOP, 0);
				break;
			case CMD_FFWD:
		        ESP_LOGI(SPP_TAG, "FFWD received");
				gpio_set_level(GPIO_FFWD, 1);
				vTaskDelay(cmdDelay / portTICK_PERIOD_MS);
				gpio_set_level(GPIO_FFWD, 0);
				break;
			case CMD_REW:
		        ESP_LOGI(SPP_TAG, "REW received");
				gpio_set_level(GPIO_REW, 1);
				vTaskDelay(cmdDelay / portTICK_PERIOD_MS);
				gpio_set_level(GPIO_REW, 0);
				break;
			case CMD_PAUSE:
		        ESP_LOGI(SPP_TAG, "PAUSE received");
				gpio_set_level(GPIO_PAUSE, 1);
				vTaskDelay(cmdDelay / portTICK_PERIOD_MS);
				gpio_set_level(GPIO_PAUSE, 0);
				break;
			case CMD_AUTO_MUTE:
		        ESP_LOGI(SPP_TAG, "AUTO_MUTE received");
				gpio_set_level(GPIO_AUTO_MUTE, 1);
				vTaskDelay(cmdDelay / portTICK_PERIOD_MS);
				gpio_set_level(GPIO_AUTO_MUTE, 0);
				break;
			case CMD_REC_FWD:
		        ESP_LOGI(SPP_TAG, "REC-FWD received");
		        switch(rec_stby_mode){
					case REC_STDBY_MODE_TECHNICS:
						gpio_set_level(GPIO_REC, 1);
						gpio_set_level(GPIO_PAUSE, 1);
						gpio_set_level(GPIO_PLAY_FWD, 1);
				        ESP_LOGI(SPP_TAG, "REC_STDBY_MODE_TECHNICS");
						break;
					case REC_STDBY_MODE_AKAI:
						gpio_set_level(GPIO_REC, 1);
						gpio_set_level(GPIO_PAUSE, 1);
				        ESP_LOGI(SPP_TAG, "REC_STDBY_MODE_AKAI");
						break;
					case REC_STDBY_MODE_PIONEER:
						gpio_set_level(GPIO_PAUSE, 1);
						gpio_set_level(GPIO_REC, 1);
						gpio_set_level(GPIO_PLAY_FWD, 1);
				        ESP_LOGI(SPP_TAG, "REC_STDBY_MODE_PIONEER");
						break;
					case REC_STDBY_MODE_TASCAM:
						gpio_set_level(GPIO_PAUSE, 1);
						gpio_set_level(GPIO_REC, 1);
						gpio_set_level(GPIO_PLAY_FWD, 1);
				        ESP_LOGI(SPP_TAG, "REC_STDBY_MODE_TASCAM");
						break;
					default:
						gpio_set_level(GPIO_REC, 0);
						gpio_set_level(GPIO_PAUSE, 0);
						gpio_set_level(GPIO_PLAY_FWD, 0);
						gpio_set_level(GPIO_PLAY_REV, 0);
				        ESP_LOGW(SPP_TAG, "REC_STDBY_MODE_UNKNOWN");
						break;
		        }
				vTaskDelay(cmdDelay / portTICK_PERIOD_MS);
				gpio_set_level(GPIO_PLAY_FWD, 0);
				gpio_set_level(GPIO_PAUSE, 0);
				gpio_set_level(GPIO_REC, 0);
				break;
				case CMD_REC_REV:
			        ESP_LOGI(SPP_TAG, "REC-REV received");
			        switch(rec_stby_mode){
						case REC_STDBY_MODE_TECHNICS:
							gpio_set_level(GPIO_REC, 1);
							gpio_set_level(GPIO_PAUSE, 1);
							gpio_set_level(GPIO_PLAY_REV, 1);
					        ESP_LOGI(SPP_TAG, "REC_STDBY_MODE_TECHNICS");
							break;
						case REC_STDBY_MODE_AKAI:
							gpio_set_level(GPIO_REC, 1);
							gpio_set_level(GPIO_PAUSE, 1);
					        ESP_LOGI(SPP_TAG, "REC_STDBY_MODE_AKAI");
							break;
						case REC_STDBY_MODE_PIONEER:
							gpio_set_level(GPIO_PAUSE, 1);
							gpio_set_level(GPIO_REC, 1);
							gpio_set_level(GPIO_PLAY_REV, 1);
					        ESP_LOGI(SPP_TAG, "REC_STDBY_MODE_PIONEER");
							break;
						case REC_STDBY_MODE_TASCAM:
							gpio_set_level(GPIO_PAUSE, 1);
							gpio_set_level(GPIO_REC, 1);
							gpio_set_level(GPIO_PLAY_REV, 1);
					        ESP_LOGI(SPP_TAG, "REC_STDBY_MODE_TASCAM");
							break;
						default:
							gpio_set_level(GPIO_REC, 0);
							gpio_set_level(GPIO_PAUSE, 0);
							gpio_set_level(GPIO_PLAY_FWD, 0);
							gpio_set_level(GPIO_PLAY_REV, 0);
					        ESP_LOGW(SPP_TAG, "REC_STDBY_MODE_UNKNOWN");
							break;
			        }
					vTaskDelay(cmdDelay / portTICK_PERIOD_MS);
					gpio_set_level(GPIO_PLAY_REV, 0);
					gpio_set_level(GPIO_PAUSE, 0);
					gpio_set_level(GPIO_REC, 0);
					break;
			default: // Error - Switch all off
		        ESP_LOGE(SPP_TAG, "UNKNOWN_COMMAND received");
				gpio_set_level(GPIO_PLAY_FWD, 0);
				gpio_set_level(GPIO_PLAY_REV, 0);
				gpio_set_level(GPIO_STOP, 0);
				gpio_set_level(GPIO_FFWD, 0);
				gpio_set_level(GPIO_REW, 0);
				gpio_set_level(GPIO_REC, 0);
				gpio_set_level(GPIO_AUTO_MUTE, 0);
				gpio_set_level(GPIO_PAUSE, 0);
				break;

		}
		bt_data_len = 0; // Reset data pointer
}

static void esp_spp_cb(esp_spp_cb_event_t event, esp_spp_cb_param_t *param)
{
    switch (event) {
    case ESP_SPP_INIT_EVT:
        ESP_LOGI(SPP_TAG, "ESP_SPP_INIT_EVT");
        esp_bt_dev_set_device_name(DEVICE_NAME);
        esp_bt_gap_set_scan_mode(ESP_BT_CONNECTABLE, ESP_BT_GENERAL_DISCOVERABLE);
        esp_spp_start_srv(sec_mask,role_slave, 0, SPP_SERVER_NAME);
        break;
    case ESP_SPP_DISCOVERY_COMP_EVT:
        ESP_LOGI(SPP_TAG, "ESP_SPP_DISCOVERY_COMP_EVT");
        break;
    case ESP_SPP_OPEN_EVT:
        ESP_LOGI(SPP_TAG, "ESP_SPP_OPEN_EVT");
        bt_open = true;
        break;
    case ESP_SPP_CLOSE_EVT:
        ESP_LOGI(SPP_TAG, "ESP_SPP_CLOSE_EVT");
        bt_open = false;
        break;
    case ESP_SPP_START_EVT:
        ESP_LOGI(SPP_TAG, "ESP_SPP_START_EVT");
        break;
    case ESP_SPP_CL_INIT_EVT:
        ESP_LOGI(SPP_TAG, "ESP_SPP_CL_INIT_EVT");
        break;
    case ESP_SPP_DATA_IND_EVT:
        ESP_LOGI(SPP_TAG, "ESP_SPP_DATA_IND_EVT len=%d handle=%d",
                 param->data_ind.len, param->data_ind.handle);
        esp_log_buffer_hex("",param->data_ind.data,param->data_ind.len);
        bt_data_len = param->data_ind.len;
        if (bt_data_len) {
        	// Copy received data to the buffer
            for(int i = 0; i < bt_data_len; i++) {
            	bt_data[i] = param->data_ind.data[i];
            }
            // Parse the buffer
            // Data will always be received in pairs: command + data
            for(int i = 0; i < bt_data_len; i++) {
            	switch(bt_data[i]){
            	case CMD_SET_REC_STDBY_MODE:
            		i++; // increment pointer
            		rec_stby_mode = bt_data[i]; // read data
                    ESP_LOGI(SPP_TAG, "Setting rec_stby to: 0x%02X", rec_stby_mode);
            		break;
            	case CMD_SET_DELAY:
            		i++; // increment pointer
            		cmdDelay = bt_data[i]; // read data
                    ESP_LOGI(SPP_TAG, "Setting delay to: %d ms", cmdDelay);
            		break;
            	case CMD_SET_PWM:
            		i++; // increment pointer
            		ledc_duty = ((LEDC_DUTY_RES / 100) * bt_data[i]); // read data
                    ESP_LOGI(SPP_TAG, "Setting LED brightness to: %d%%", (ledc_duty / 10));
            		break;
            	case CMD_TRANSPORT_FUNCTION:
            		i++; // increment pointer
            		send_ctrl(bt_data[i]); // read data
            		break;
            	default:
            		break;
            	}

            }
        }
        break;
    case ESP_SPP_CONG_EVT:
        ESP_LOGI(SPP_TAG, "ESP_SPP_CONG_EVT");
        break;
    case ESP_SPP_WRITE_EVT:
        ESP_LOGI(SPP_TAG, "ESP_SPP_WRITE_EVT");
        break;
    case ESP_SPP_SRV_OPEN_EVT:
        ESP_LOGI(SPP_TAG, "ESP_SPP_SRV_OPEN_EVT");
        //gettimeofday(&time_old, NULL);
        bt_open = true;
        break;
    case ESP_SPP_SRV_STOP_EVT:
        ESP_LOGI(SPP_TAG, "ESP_SPP_SRV_STOP_EVT");
        bt_open = false;
        break;
    case ESP_SPP_UNINIT_EVT:
        ESP_LOGI(SPP_TAG, "ESP_SPP_UNINIT_EVT");
        break;
    default:
        break;
    }
}

void esp_bt_gap_cb(esp_bt_gap_cb_event_t event, esp_bt_gap_cb_param_t *param)
{
    switch (event) {
    case ESP_BT_GAP_AUTH_CMPL_EVT:{
        if (param->auth_cmpl.stat == ESP_BT_STATUS_SUCCESS) {
            ESP_LOGI(SPP_TAG, "authentication success: %s", param->auth_cmpl.device_name);
            esp_log_buffer_hex(SPP_TAG, param->auth_cmpl.bda, ESP_BD_ADDR_LEN);
        } else {
            ESP_LOGE(SPP_TAG, "authentication failed, status:%d", param->auth_cmpl.stat);
        }
        break;
    }
    case ESP_BT_GAP_PIN_REQ_EVT:{
        ESP_LOGI(SPP_TAG, "ESP_BT_GAP_PIN_REQ_EVT min_16_digit:%d", param->pin_req.min_16_digit);
        if (param->pin_req.min_16_digit) {
            ESP_LOGI(SPP_TAG, "Input pin code: 0000 0000 0000 0000");
            esp_bt_pin_code_t pin_code = {0};
            esp_bt_gap_pin_reply(param->pin_req.bda, true, 16, pin_code);
        } else {
            ESP_LOGI(SPP_TAG, "Input pin code: 1234");
            esp_bt_pin_code_t pin_code;
            pin_code[0] = '1';
            pin_code[1] = '2';
            pin_code[2] = '3';
            pin_code[3] = '4';
            esp_bt_gap_pin_reply(param->pin_req.bda, true, 4, pin_code);
        }
        break;
    }

#if (CONFIG_BT_SSP_ENABLED == true)
    case ESP_BT_GAP_CFM_REQ_EVT:
        ESP_LOGI(SPP_TAG, "ESP_BT_GAP_CFM_REQ_EVT Please compare the numeric value: %d", param->cfm_req.num_val);
        esp_bt_gap_ssp_confirm_reply(param->cfm_req.bda, true);
        break;
    case ESP_BT_GAP_KEY_NOTIF_EVT:
        ESP_LOGI(SPP_TAG, "ESP_BT_GAP_KEY_NOTIF_EVT passkey:%d", param->key_notif.passkey);
        break;
    case ESP_BT_GAP_KEY_REQ_EVT:
        ESP_LOGI(SPP_TAG, "ESP_BT_GAP_KEY_REQ_EVT Please enter passkey!");
        break;
#endif

    case ESP_BT_GAP_MODE_CHG_EVT:
        ESP_LOGI(SPP_TAG, "ESP_BT_GAP_MODE_CHG_EVT mode:%d", param->mode_chg.mode);
        break;

    default: {
        ESP_LOGI(SPP_TAG, "event: %d", event);
        break;
    }
    }
    return;
}

void getMAC_Address(void){
    uint8_t mac_addr[6] = {0};
    esp_err_t ret = ESP_OK;
    //Get base MAC address from EFUSE BLK0
    ret = esp_efuse_mac_get_default(mac_addr);
    if (ret != ESP_OK) {
        ESP_LOGE(SPP_TAG, "Failed to get base MAC address from EFUSE BLK0. (%s)", esp_err_to_name(ret));
        ESP_LOGE(SPP_TAG, "Aborting");
        abort();
    } else {
        ESP_LOGI(SPP_TAG, "Base MAC Address read from EFUSE BLK0");
        ESP_LOGI("Base MAC", "\"%02X:%02X:%02X:%02X:%02X:%02X\"",
        		mac_addr[0], mac_addr[1], mac_addr[2],
				mac_addr[3], mac_addr[4], mac_addr[5]);
    }
    //Get MAC address for Bluetooth
    ESP_ERROR_CHECK(esp_read_mac(mac_addr, ESP_MAC_BT));
    ESP_LOGI("BT MAC", "   %02X:%02X:%02X:%02X:%02X:%02X",
             mac_addr[0], mac_addr[1], mac_addr[2],
             mac_addr[3], mac_addr[4], mac_addr[5]);
}

void app_main(void)
{
    esp_err_t ret = nvs_flash_init();
    if (ret == ESP_ERR_NVS_NO_FREE_PAGES || ret == ESP_ERR_NVS_NEW_VERSION_FOUND) {
        ESP_ERROR_CHECK(nvs_flash_erase());
        ret = nvs_flash_init();
    }
    ESP_ERROR_CHECK( ret );

    ESP_ERROR_CHECK(esp_bt_controller_mem_release(ESP_BT_MODE_BLE));

    esp_bt_controller_config_t bt_cfg = BT_CONTROLLER_INIT_CONFIG_DEFAULT();
    if ((ret = esp_bt_controller_init(&bt_cfg)) != ESP_OK) {
        ESP_LOGE(SPP_TAG, "%s initialise controller failed: %s\n", __func__, esp_err_to_name(ret));
        return;
    }

    if ((ret = esp_bt_controller_enable(ESP_BT_MODE_CLASSIC_BT)) != ESP_OK) {
        ESP_LOGE(SPP_TAG, "%s enable controller failed: %s\n", __func__, esp_err_to_name(ret));
        return;
    }

    if ((ret = esp_bluedroid_init()) != ESP_OK) {
        ESP_LOGE(SPP_TAG, "%s initialise bluedroid failed: %s\n", __func__, esp_err_to_name(ret));
        return;
    }

    if ((ret = esp_bluedroid_enable()) != ESP_OK) {
        ESP_LOGE(SPP_TAG, "%s enable bluedroid failed: %s\n", __func__, esp_err_to_name(ret));
        return;
    }

    if ((ret = esp_bt_gap_register_callback(esp_bt_gap_cb)) != ESP_OK) {
        ESP_LOGE(SPP_TAG, "%s gap register failed: %s\n", __func__, esp_err_to_name(ret));
        return;
    }

    if ((ret = esp_spp_register_callback(esp_spp_cb)) != ESP_OK) {
        ESP_LOGE(SPP_TAG, "%s spp register failed: %s\n", __func__, esp_err_to_name(ret));
        return;
    }

    if ((ret = esp_spp_init(esp_spp_mode)) != ESP_OK) {
        ESP_LOGE(SPP_TAG, "%s spp init failed: %s\n", __func__, esp_err_to_name(ret));
        return;
    }

#if (CONFIG_BT_SSP_ENABLED == true)
    /* Set default parameters for Secure Simple Pairing */
    esp_bt_sp_param_t param_type = ESP_BT_SP_IOCAP_MODE;
    esp_bt_io_cap_t iocap = ESP_BT_IO_CAP_IO;
    esp_bt_gap_set_security_param(param_type, &iocap, sizeof(uint8_t));
#endif

    /*
     * Set default parameters for Legacy Pairing
     * Use variable pin, input pin code when pairing
     */
    esp_bt_pin_type_t pin_type = ESP_BT_PIN_TYPE_VARIABLE;
    esp_bt_pin_code_t pin_code;
    esp_bt_gap_set_pin(pin_type, 0, pin_code);

    printf("\n------------------------------------------------------\n");
    ESP_LOGI(SPP_TAG, "Firmware version: %s", APP_VERSION);
    //printf("Firmware version: %s", APP_VERSION);
    printf("------------------------------------------------------\n\n");

    /*
     * Prepare and set configuration of timers
     * that will be used by LED Controller
     */
    ledc_timer_config_t ledc_timer = {
        .duty_resolution = LEDC_TIMER_10_BIT, // resolution of PWM duty
        .freq_hz = 5000,                      // frequency of PWM signal
        .speed_mode = LEDC_HS_MODE,           // timer mode
        .timer_num = LEDC_HS_TIMER,            // timer index
        .clk_cfg = LEDC_AUTO_CLK,              // Auto select the source clock
    };
    // Set configuration of timer0 for high speed channels
    ledc_timer_config(&ledc_timer);
    /*
     * Prepare individual configuration
     * for each channel of LED Controller
     * by selecting:
     * - controller's channel number
     * - output duty cycle, set initially to 0
     * - GPIO number where LED is connected to
     * - speed mode, either high or low
     * - timer servicing selected channel
     *   Note: if different channels use one timer,
     *         then frequency and bit_num of these channels
     *         will be the same
     */
    ledc_channel_config_t ledc_channel = {
            .channel    = LEDC_HS_CH0_CHANNEL,
            .duty       = 0,
            .gpio_num   = LEDC_HS_CH0_GPIO,
            .speed_mode = LEDC_HS_MODE,
            .hpoint     = 0,
            .timer_sel  = LEDC_HS_TIMER
        };
    ledc_channel_config(&ledc_channel);




    /* Configure the IOMUX register for GPIO */
    printf("Selecting GPIOs...\n");
    gpio_pad_select_gpio(GPIO_PLAY_FWD);
    gpio_pad_select_gpio(GPIO_PLAY_REV);
    gpio_pad_select_gpio(GPIO_STOP);
    gpio_pad_select_gpio(GPIO_FFWD);
    gpio_pad_select_gpio(GPIO_REW);
    gpio_pad_select_gpio(GPIO_REC);
    gpio_pad_select_gpio(GPIO_AUTO_MUTE);
    gpio_pad_select_gpio(GPIO_PAUSE);
    //gpio_pad_select_gpio(GPIO_BT_OPEN);

    printf("Done!\n\n");

    /* Set the GPIO as input/output, in case we need feedback to the app in the future */
    printf("Setting GPIOs to outputs...\n");
    gpio_set_direction(GPIO_PLAY_FWD, GPIO_MODE_INPUT_OUTPUT);
    gpio_set_direction(GPIO_PLAY_REV, GPIO_MODE_INPUT_OUTPUT);
    gpio_set_direction(GPIO_STOP, GPIO_MODE_INPUT_OUTPUT);
    gpio_set_direction(GPIO_FFWD, GPIO_MODE_INPUT_OUTPUT);
    gpio_set_direction(GPIO_REW, GPIO_MODE_INPUT_OUTPUT);
    gpio_set_direction(GPIO_REC, GPIO_MODE_INPUT_OUTPUT);
    gpio_set_direction(GPIO_AUTO_MUTE, GPIO_MODE_INPUT_OUTPUT);
    gpio_set_direction(GPIO_PAUSE, GPIO_MODE_INPUT_OUTPUT);
    //gpio_set_direction(GPIO_BT_OPEN, GPIO_MODE_INPUT_OUTPUT);

    printf("Done!\n\n");
    printf("%s is running...\n\n", SPP_TAG);

    getMAC_Address(); // Read and display BT MAC address.

    while (1) {
/*
        gpio_set_level(GPIO_BT_OPEN, 1);
        vTaskDelay(cmdDelay / portTICK_PERIOD_MS);
        gpio_set_level(GPIO_BT_OPEN, 0);
        if(!bt_open) {
            vTaskDelay((1000 - cmdDelay) / portTICK_PERIOD_MS); // Fast blink when not connected
        }else{
            vTaskDelay((5000 - cmdDelay) / portTICK_PERIOD_MS); // Slow blink when connected

        }
*/
		ledc_set_duty(ledc_channel.speed_mode, ledc_channel.channel, ledc_duty);
		ledc_update_duty(ledc_channel.speed_mode, ledc_channel.channel);
		vTaskDelay(cmdDelay / portTICK_PERIOD_MS);
		ledc_set_duty(ledc_channel.speed_mode, ledc_channel.channel, 0);
		ledc_update_duty(ledc_channel.speed_mode, ledc_channel.channel);
		if(!bt_open) {
			vTaskDelay((1000 - cmdDelay) / portTICK_PERIOD_MS); // Fast blink when not connected
		}else{
			vTaskDelay((5000 - cmdDelay) / portTICK_PERIOD_MS); // Slow blink when connected

		}
    }
}

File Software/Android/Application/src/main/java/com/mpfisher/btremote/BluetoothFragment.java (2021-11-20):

/*
 * Copyright (C) 2021 mpfisher.com R2R BT Remote Project
 *
 * Licensed under the Apache License, Version 2.0 (the "License");
 * you may not use this file except in compliance with the License.
 * You may obtain a copy of the License at
 *
 *      http://www.apache.org/licenses/LICENSE-2.0
 *
 * Unless required by applicable law or agreed to in writing, software
 * distributed under the License is distributed on an "AS IS" BASIS,
 * WITHOUT WARRANTIES OR CONDITIONS OF ANY KIND, either express or implied.
 * See the License for the specific language governing permissions and
 * limitations under the License.
 *
 */
/*
 *
 * v.1.0.7 2021/09/26
 * Implemented REC_FWD and REC_REV commands
 * Added tap&hold event handler for REC button
 * REC_ARMED button removed
 * Added LED brightness settings option
 * All command values changed. !!!Update the receiver!!!
 * Added scaling of the function buttons for different screen sizes
 *
 * TODO
 *  Implement state machine sync.
 *  Drop the use of fragments and move everything to the main activity.
 *
 *
 */

package com.mpfisher.btremote;

import android.app.ActionBar;
import android.app.Activity;
import android.bluetooth.BluetoothAdapter;
import android.bluetooth.BluetoothDevice;
import android.content.Intent;
import android.os.Bundle;
import android.os.Handler;
import android.os.Message;
import android.view.LayoutInflater;
import android.view.Menu;
import android.view.MenuInflater;
import android.view.MenuItem;
import android.view.View;
import android.view.ViewGroup;
import android.widget.ImageButton;
import android.widget.ImageView;
import android.widget.TextView;
import android.widget.Toast;

import androidx.annotation.NonNull;
import androidx.annotation.Nullable;
import androidx.fragment.app.Fragment;
import androidx.fragment.app.FragmentActivity;

//import com.mpfisher.btremote.R;
import com.mpfisher.common.logger.Log;

/**
 * This fragment controls Bluetooth to communicate with other devices.
 */
public class BluetoothFragment extends Fragment {

    private static final String TAG = "BT-RemoteFragment";

    // Intent request codes
    private static final int REQUEST_CONNECT_DEVICE_SECURE = 1;
    private static final int REQUEST_CONNECT_DEVICE_INSECURE = 2;
    private static final int REQUEST_ENABLE_BT = 3;

    private ImageButton mRecButton;
    private ImageButton mRewButton;
    private ImageButton mPlayButton;
    private ImageButton mFfwdButton;
    private ImageButton mStopButton;
    private ImageButton mPauseButton;
    private ImageButton mAutoMuteButton;
    private ImageButton mPlayFwdButton;
    private ImageButton mPlayRevButton;

    private TextView machineNameLabel;
    // Tape transport functions
    private static final byte CMD_REC_FWD      = 0x01;
    private static final byte CMD_REC_REV      = 0x02;
    private static final byte CMD_PAUSE        = 0x03;
    private static final byte CMD_PLAY_FWD     = 0x04;
    private static final byte CMD_PLAY_REV     = 0x05;
    private static final byte CMD_STOP         = 0x06;
    private static final byte CMD_FFWD         = 0x07;
    private static final byte CMD_REW          = 0x08;
    private static final byte CMD_AUTO_MUTE    = 0x09;
    private static final byte CMD_TRANSPORT_FUNCTION   = (byte) (0xAA & 0xFF);
    // Receiver config
    private static final byte CMD_SET_REC_STDBY_MODE   = (byte) (0xBB & 0xFF);
    private static final byte REC_STDBY_MODE_TECHNICS  = 0x01;
    private static final byte REC_STDBY_MODE_AKAI      = 0x02;
    private static final byte REC_STDBY_MODE_PIONEER   = 0x04;
    private static final byte REC_STDBY_MODE_TASCAM    = 0x08;

    private static final byte CMD_SET_DELAY    = (byte) (0xBA & 0xFF);
    private static final byte CMD_SET_LED_PWM  = (byte) (0xCA & 0xFF);
    // Name of the connected device
    private String mConnectedDeviceName = null;
    // TODO: State machine sync.
    //private static final byte ACK = (byte)  (0xEF & 0xFF);

     // Byte buffer for outgoing messages
    //private byte[] mOutBuffer;

    /**
     * Local Bluetooth adapter
     */
    private BluetoothAdapter mBluetoothAdapter = null;

    /**
     * Member objects for BT services
     */
    private BluetoothService mBTService = null;

    private MenuItem menu_icon_bt = null;
    private boolean rec_on = false;
    private boolean rec_long_press = false;
    private byte delay = 100; // Holds delay value read from preferences
    private byte pwm = 100; // Holds pwm value (Bluetooth LED brightness) read from preferences
    private byte RecStdbyMode = REC_STDBY_MODE_TECHNICS;

    @Override
    public void onCreate(Bundle savedInstanceState) {
        super.onCreate(savedInstanceState);
        setHasOptionsMenu(true);
        // Get local Bluetooth adapter
        mBluetoothAdapter = BluetoothAdapter.getDefaultAdapter();

        // If the adapter is null, then Bluetooth is not supported
        FragmentActivity activity = getActivity();
        if (mBluetoothAdapter == null && activity != null) {
            Toast.makeText(activity, "Bluetooth is not available", Toast.LENGTH_LONG).show();
            activity.finish();
        }
    }

    @Override
    public void onStart() {
        super.onStart();

        FragmentActivity activity = getActivity();

        // Read preference values and setup the app
        //
        // Machine name label. Set by user
        final String machineName = Utils.getPrefence(activity,
                getString(R.string.prefkey_machine_name));
        machineNameLabel.setText(machineName);
        Log.d(TAG, "Loaded prefkey_machine_name, \""+machineNameLabel.getText()+"\"");

        // Show "AUTO MUTE" button?
        if (Utils.getBooleanPrefence(activity,
                getString(R.string.prefkey_show_rec_mute))) {
            mAutoMuteButton.setVisibility(View.VISIBLE);
            Log.d(TAG, "Loaded prefkey_show_rec_mute, true");
        }else{
            mAutoMuteButton.setVisibility(View.INVISIBLE);
            Log.d(TAG, "Loaded prefkey_show_rec_mute, false");
        }

        // Show "PLAY_REV" button?
        if (Utils.getBooleanPrefence(activity,
                getString(R.string.prefkey_show_play_rev))) {
            mPlayButton.setVisibility(View.GONE);
            mPlayFwdButton.setVisibility(View.VISIBLE);
            mPlayRevButton.setVisibility(View.VISIBLE);
            Log.d(TAG, "Loaded prefkey_show_play_rev, true");
        }else{
            mPlayButton.setVisibility(View.VISIBLE);
            mPlayFwdButton.setVisibility(View.GONE);
            mPlayRevButton.setVisibility(View.GONE);
            Log.d(TAG, "Loaded prefkey_show_play_rev, false");
        }
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
